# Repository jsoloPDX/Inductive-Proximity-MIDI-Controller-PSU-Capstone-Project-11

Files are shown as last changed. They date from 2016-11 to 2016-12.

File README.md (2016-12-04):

# MIDI-THEREMIN-Controller
A theremin style controller for MIDI devices
A Senior ECE practicum project for Portland State University

Background

Most electronic musical instruments are controlled by small motions such as knob-turns or button-pushes. Such actions tend to be neither as interesting to watch nor as expressive as, for example, a guitarist strumming or a drummer drumming (or a piper piping). Using hand gestures and arm motions to control musical instruments would allow more precise and expressive control of electronic instrument parameters. The theremin, an analog electronic instrument can be controlled by hand gestures, but it’s ability to interface with modern equipment is lacking and or restrictive.

Objective

Our objective is to update the Theremin-style analog instrument to contain digital features, mainly a MIDI output. This will allow it to expressively control all kinds of modern musical instruments and equipment.

HOW IT SHOULD WORK:
An analog theremin circuit will send proximity information to a Microcontroller. The Microcontroller will organize, process, and convert that information into MIDI data, which will be sent to a MIDI capable device VIA a standard MIDI or USB MIDI connector. There is some room for automation as far as built in “calibration” sequences to adjust the sensitivity of the coils. The device will be somewhat modular in design and construction, which will allow for expansion of the variety of proximity sensors used and versatility of output signals.

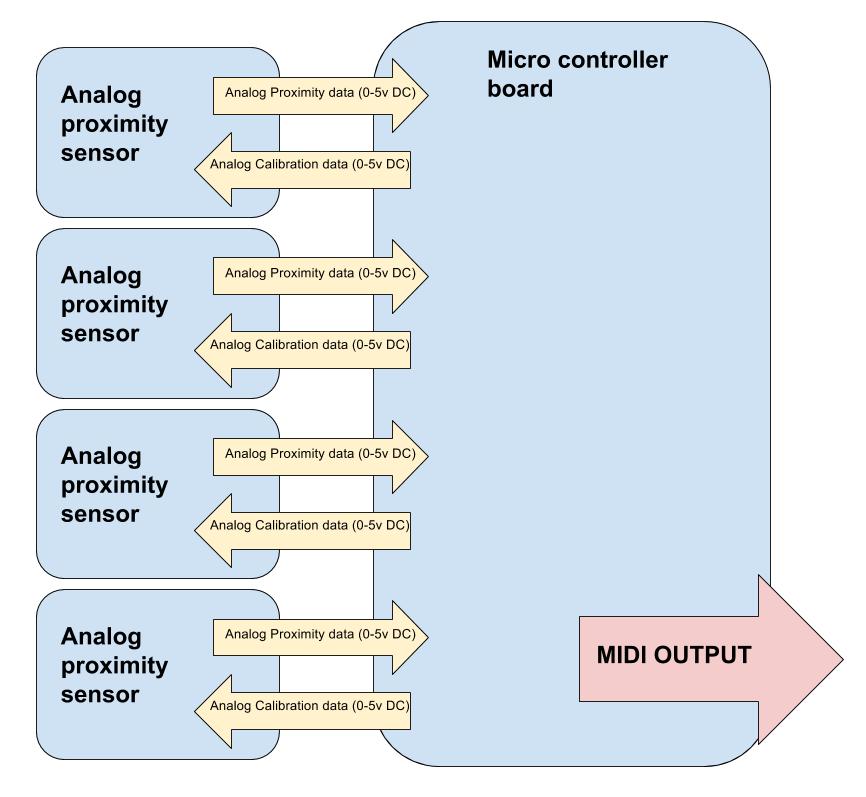
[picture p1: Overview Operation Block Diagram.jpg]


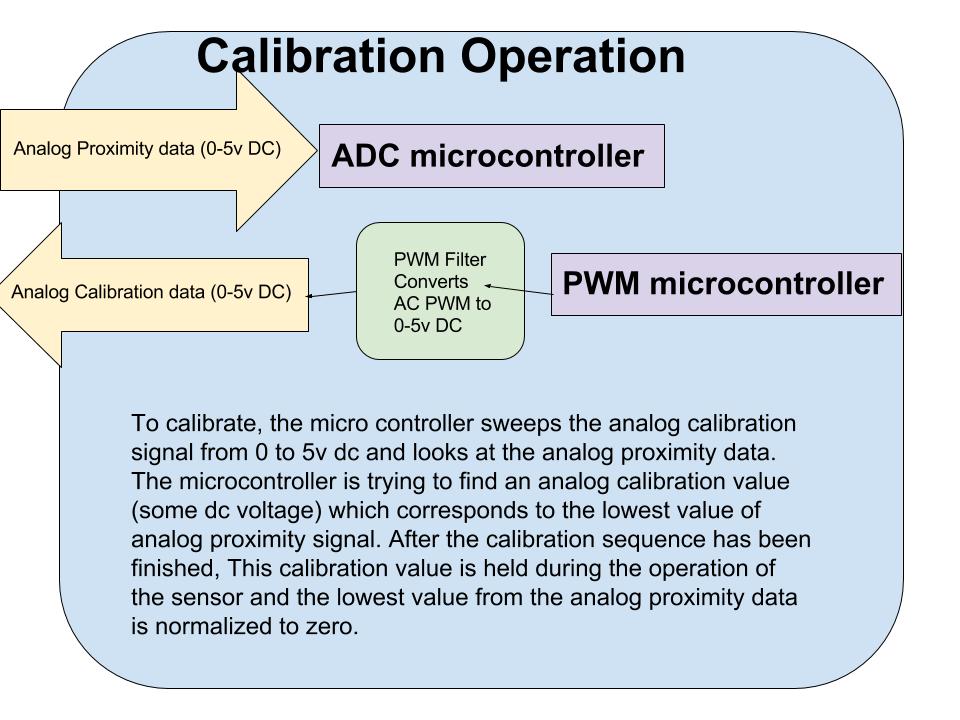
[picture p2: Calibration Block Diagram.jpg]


The code library "Arduino_MIDI_Library_v4.2.zip" is not our work and is taken from the project at: https://github.com/FortySevenEffects/arduino_midi_library/

The EagleCAD library "adafruit-Adafruit-Eagle-Library-4abf84c.zip" is not our work and is taken from the project at:
https://github.com/adafruit/Adafruit-Eagle-Library

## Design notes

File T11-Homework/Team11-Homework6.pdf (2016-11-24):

## ECE-411 Homework 6

## Practicum Team 11

Eric Bennett, Casey Montgomery, James Solonika, Charles Staffeld Instructor: Mark Faust
11/22/2016

System Tests

1. CPU Board Functional Checks
1.1. Power on indicator
1.2. Power supply voltages and current levels
1.3. Mode button and indicators
2. Sensor Board Functional Checks
2.1. Power supply voltages
2.2. Local oscillator accuracy
2.3. Pitch oscillator
2.3.1. Stable behavior
2.3.2. Detection range
2.4. Filter behavior
2.5. MISO voltage
3. Calibration Functionality Check
3.1. Run calibration function
3.2. Remeasure MISO
4. Functional Mode Checks
4.1. Mode 1
4.2. Mode 2
4.3. Mode 3
5. MIDI Control Checks
5.1. Mode 1
5.2. Mode 2
5.3. Mode 3

Test Writer: James Solonika / Charles Staffeld

Test Case Name: | CPU Board Functional Checks | Test ID#: | CPU-FC
Description: | Checks to determine if the CPU board has power and basic functionality. Does not test any user modes. | Type: | Black Box

Tester Information

Name of Tester: | | Date:
Hardware Ver: | | Time:
Setup: | CPU board should begin unplugged, 12V DC adapter with barrel jack and DMM should be available.
Step | Action | Expected Result | Pass | Fail | N/A | Comments
1 | Plug in board. | Mode 1 LED (LED 2) should light up.
2 | Measure +12V test point with DMM. | Meter should read +12V ± 0.5. Current should be < 200mA.
3 | Measure +5V test point with DMM. | Meter should read +5V ± 0.5. Current should be < 40 mA.
4 | Press mode button (SW 1) repeatedly. | LEDs will light up one at a time in this order: LED 2, 3, 4, 5, then repeat.

Overall Test Result:

Test Writer: James Solonika / Charles Staffeld

Test Case Name: | Sensor Board Functional Checks | Test ID#: | SB-FC
Description: | Checks to determine if the Sensor board can receive power and oscillate | Type: | White Box

Tester Information

Name of Tester: | | Date:
Hardware Ver: | | Time:
Setup: | CPU board plugged in and passed CPU-FC, oscilloscope, DMM and MIDI cable available
Step | Action | Expected Result | Pass | Fail | N/A | Comments
1 | Plug MIDI cable into CPU MIDI Jack 1 and MIDI jack on sensor board . | Test point “TP_LV+”” should measure +6V± 0.5V (with respect to GND as defined on the board)
2 | Plug MIDI cable into CPU MIDI Jack 1 and MIDI jack on sensor board . | Test point “TP_PV+” should measure +6V± 0.5V (with respect to GND as defined on the board)
3 | Measure test point “TP_LV-” voltage. | Voltage should be -6V ± 0.5V. (with respect to GND as defined on the board)
4 | Measure test point “TP_PV-” voltage. | Voltage should be -6V ± 0.5V. (with respect to GND as defined on the board)
5 | Scope “TP_LOSC” | Sine wave should be 460 kHz kHz ± 10kHz

6 | Scope “TP_POSC” with hand far away from antenna | Sine wave should be 460 kHz ± 10kHz
7 | Scope “TPFOUT”. With hand far away from antenna | Sine wave should be between 1Hz and 3 kHz, but stable at that frequency
8 | Scope “TPFOUT”. While moving hand near antenna | Sine wave should vary in frequency by around 1 kHz.
9 | Scope proximity voltage output “PROXIMIT Y” | A steady DC voltage.
10 | Scope MISO test point . | Should be a flat DC signal, no AC ripple.

Overall Test Result:

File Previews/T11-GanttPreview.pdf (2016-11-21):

ID | Task Mode | Task Name | Duration | Start | Finish
1 | | Presentation | 5 days | M 12/5/16 | F 12/9/16
2 | | PCB To Fab | 1 day | T 11/17/16 | T 11/17/16
3 | | Homework 6: Test Plan Due | 1 day | T 11/22/16 | T 11/22/16
4 Homework 5: System | | Design/Modeling Due | 1 day | T 11/17/16 | T 11/17/16
5 Preliminary PCB Layout Due (No | | DRC Errors) | 1 day | T 11/10/16 | T 11/10/16
6 | | Project Schedule Due | 1 day | T 11/8/16 | T 11/8/16
7 | | Software | 19 days | M 11/7/16 | T 12/1/16
8 Complete PWM Routine for | | remaining port | 4 days | M 11/7/16 | T 11/10/16
9 | | Reduce redundancies | 3 days | F 11/11/16 | T 11/15/16
10 Test that CPU can read sensor | | output | 5 days | S 11/12/16 | T 11/17/16
11 Write routine to read | | voltage | 2 days | S 11/12/16 | S 11/13/16
12 | | Test routine | 2 days | M 11/14/16 | T 11/15/16
13 | | Optimize routine | 2 days | W 11/16/16 | T 11/17/16

James Solonika

James Solonika

James Solonika

Eric Bennett

Eric Bennett

Casey Montgomery

Casey Montgomery

Casey Montgomery

2 | 5 | 8 | 11 | 14 | 17 | 20 | 23 | 26 | 29 | 2 | 5 | 8 | 11 | 14 | 17
November 2016 | December 2016

Task
Split
Milestone
Summary
Project Summary
Inactive Task
Inactive Milestone

Inactive Summary
Manual Task
Duration-only
Manual Summary Rollup
Manual Summary
Start-only
Finish-only

External Tasks
External Milestone
Deadline
Progress
Manual Progress

Page 1

Project: T11-Gantt
Date: S 11/20/16

| Mode
14 | | Write Calibration Routine | 5 days | S 11/13/16 | F 11/18/16
15 Handle button press during | | polling | 1 day | S 11/13/16 | S 11/13/16
16 | | Write LED blinking routine | 1 day | T 11/15/16 | T 11/15/16
17 Sample frequency_voltage | | input | 2 days | W 11/16/16 | T 11/17/16
18 | | Adjust output voltage | 1 day | F 11/18/16 | F 11/18/16
19 | | Write main code | 4 days | F 11/18/16 | W 11/23/16
20 | | Cpu initialization routine | 1 day | F 11/18/16 | F 11/18/16
21 | | Write button polling | 2 days | S 11/19/16 | S 11/20/16
22 frequency_voltage input | | reading | 2 days | M 11/21/16 | T 11/22/16
23 | | Call mode statement | 1 day | W 11/23/16 | W 11/23/16
24 | | Write routine for each mode | 6 days | S 11/19/16 | M 11/28/16
25 | | Write Mode 1 | 3 days | S 11/19/16 | T 11/22/16
26 | | Write Mode 2 | 3 days | W 11/23/16 | F 11/25/16

Eric Bennett

Eric Bennett

Eric Bennett

Eric Bennett

Casey Montgomery

Casey Montgomery

Casey Montgomery

Casey Montgomery

Eric Bennett

Eric Bennett

2 | 5 | 8 | 11 | 14 | 17 | 20 | 23 | 26 | 29 | 2 | 5 | 8 | 11 | 14 | 17

Task
Split
Milestone
Summary
Project Summary
Inactive Task
Inactive Milestone

Inactive Summary
Manual Task
Duration-only
Manual Summary Rollup
Manual Summary
Start-only
Finish-only

External Tasks
External Milestone
Deadline
Progress
Manual Progress

Page 2

Project: T11-Gantt
Date: S 11/20/16

| Mode
27 | | Write Mode 3 | 3 days | T 11/24/16 | S 11/26/16
28 | | Mode switching routine | 2 days | S 11/26/16 | M 11/28/16
29 | | CPU Board Hardware | 17 days | M 11/7/16 | T 11/29/16
30 | | Test Debounce | 1 day | T 11/8/16 | T 11/8/16
31 | | Test PWM Converter | 1 day | T 11/8/16 | T 11/8/16
32 | | Finalize Board Layout | 2 days | W 11/9/16 | T 11/10/16
33 | | Generate BOM | 2 days | F 11/11/16 | S 11/13/16
34 | | Create prototype CPU board | 3 days | S 11/12/16 | T 11/15/16
35 | | Sketch out board housing | 3 days | W 11/16/16 | F 11/18/16
36 | | Create board housing | 3 days | M 11/21/16 | W 11/23/16
37 | | Sensor Board Hardware | 13 days | M 11/7/16 | W 11/23/16
38 | | Finalize Board Layout | 4 days | M 11/7/16 | T 11/10/16
39 | | Generate BOM | 2 days | F 11/11/16 | S 11/13/16

Casey Montgomery

Eric Bennett

James Solonika

James Solonika

James Solonika

James Solonika

Casey Montgomery

Casey Montgomery

Casey Montgomery

Charles Staffeld

Charles Staffeld

2 | 5 | 8 | 11 | 14 | 17 | 20 | 23 | 26 | 29 | 2 | 5 | 8 | 11 | 14 | 17

Task
Split
Milestone
Summary
Project Summary
Inactive Task
Inactive Milestone

Inactive Summary
Manual Task
Duration-only
Manual Summary Rollup
Manual Summary
Start-only
Finish-only

External Tasks
External Milestone
Deadline
Progress
Manual Progress

Page 3

Project: T11-Gantt
Date: S 11/20/16

| Mode
40 | | Sketch out board housing | 4 days | T 11/15/16 | F 11/18/16 | Charles Staffeld
41 | | Create board housing | 3 days | M 11/21/16 | W 11/23/16
42 | | Testing | 16 days | T 11/15/16 | T 12/6/16
43 Test interfacing of prototype | | boards | 3 days | T 11/15/16 | T 11/17/16
44 Test functionality of sensor | | PCB | 6 days | F 11/18/16 | F 11/25/16
45 | | Test functionality of CPU PCB | 6 days | F 11/18/16 | F 11/25/16
46 | | Test interfacing of PCBs | 5 days | M 11/28/16 | F 12/2/16

Charles Staffeld

Casey Montgomery

Charles Staffeld

James Solonika

Casey Montgomery

2 | 5 | 8 | 11 | 14 | 17 | 20 | 23 | 26 | 29 | 2 | 5 | 8 | 11 | 14 | 17

Task
Split
Milestone
Summary
Project Summary
Inactive Task
Inactive Milestone

Inactive Summary
Manual Task
Duration-only
Manual Summary Rollup
Manual Summary
Start-only
Finish-only

External Tasks
External Milestone
Deadline
Progress
Manual Progress

Page 4

Project: T11-Gantt
Date: S 11/20/16

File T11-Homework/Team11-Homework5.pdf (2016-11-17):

## ECE-411 Homework 5 Practicum Team 11

Eric Bennett, Casey Montgomery, James Solonika, Charles Staffeld Instructor: Mark Faust
11/17/2016

UML Physical View:

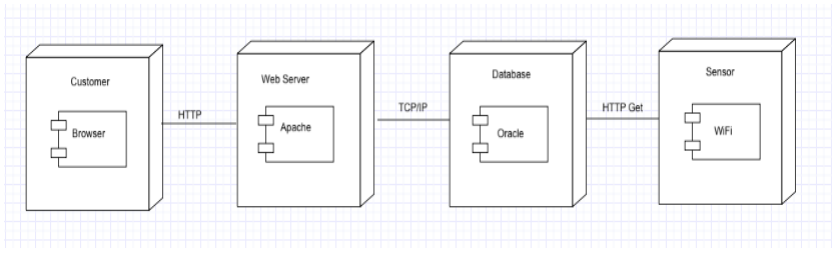
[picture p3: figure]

Simple physical system overview. Customer will not interact with the sensor directly, but pull data from a website in a browser.

UML Class Diagram:

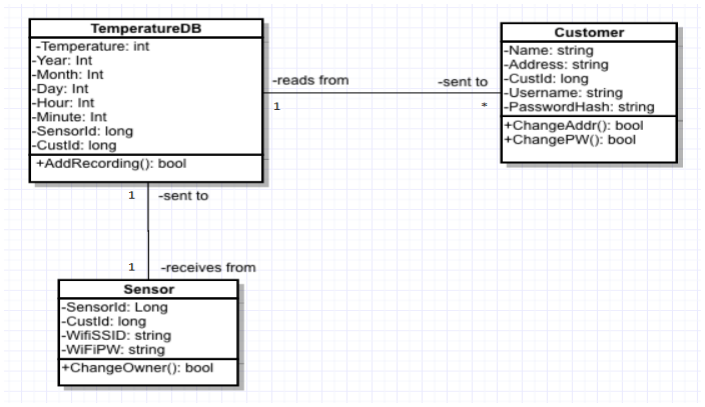
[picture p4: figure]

Decisions: CustId is included in each sensor and TemperatureDB entry to indicate the owner of the sensor and/or data. Sensor entry can be created when a sensor is manufactured and when other data are filled in during registration. WiFi information is to be stored with the sensor data to aid in adding new sensors or replacing a broken sensor. All time information is stored as separate values to simplify SQL sort and search actions.

Use Case:

Use-Case | Adding a Vaccine Temperature Sensor
Actors | Customer, Database, WebServer, Sensor
Description | This use-case occurs when a customer registers a vaccine temperature sensor. For new customers, the WebServer has them create an account, stores that information in the database, then adds their CustomerID to a sensor entry. If they are an existing customer, they are asked to verify their information then their CustomerID is added to a sensor entry. They are also asked if they would like to use the WiFi information from any of their previously registered devices.
Stimulus | Sensor registration via the WebServer
Response | Verify that sensor is connected to WiFi and can communicate with the Database

Activity View of sensor wake up and transmit:

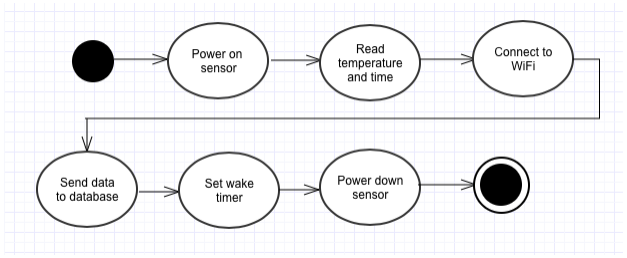
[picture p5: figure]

A wake timer is used to collect data at intervals of time instead of the sensor being woken by an outside system in order to reduce quiescent current (save power). If WiFi or the database cannot be contacted, that data its stored locally and sent with the next transmission.

HTTP GET string specification:

Upon waking, the sensor will send data to the database using a HTTP GET url in the form:

GET
/AddRecording.cgi?Temperature=value1&Year=value2&Month=value3&Day=value3&Hour=v alue4&Minute=value5&SensorId=value6

The server should be able to record all sent data into a database entry and use the SensorId to find the CustomerId that owns that sensor, then add that into the TemperatureDB entry.

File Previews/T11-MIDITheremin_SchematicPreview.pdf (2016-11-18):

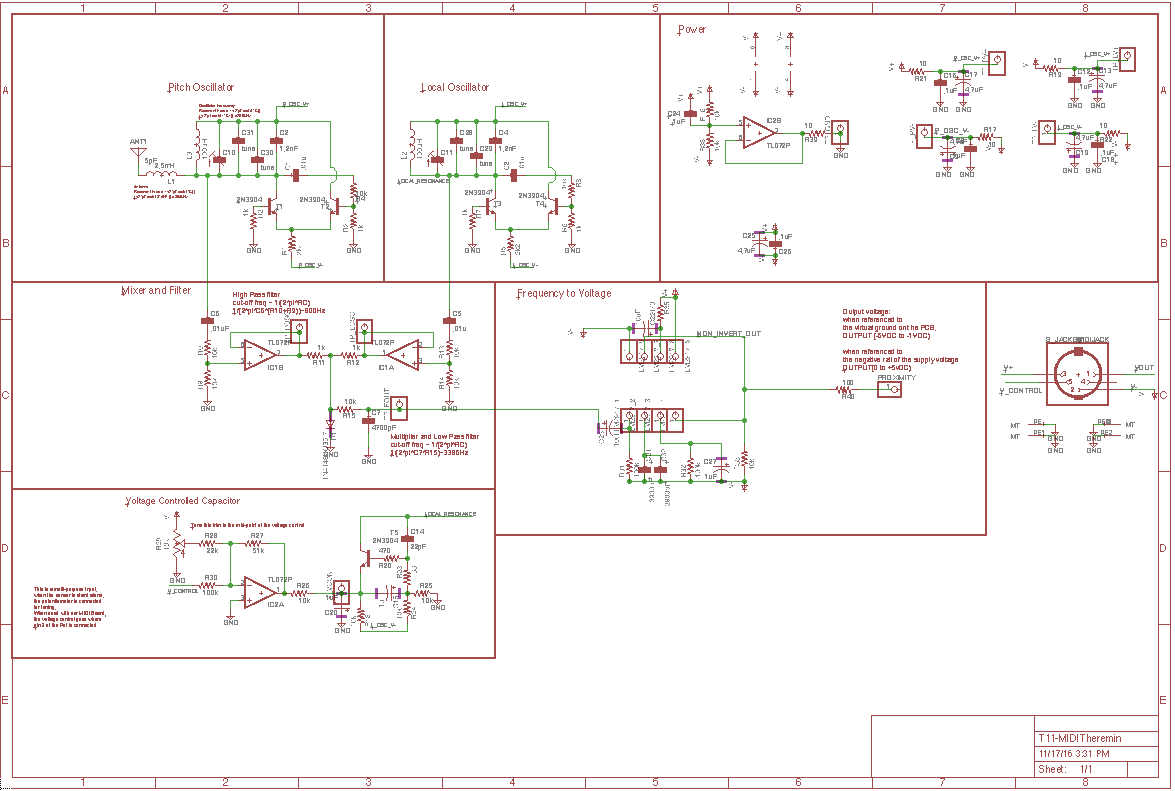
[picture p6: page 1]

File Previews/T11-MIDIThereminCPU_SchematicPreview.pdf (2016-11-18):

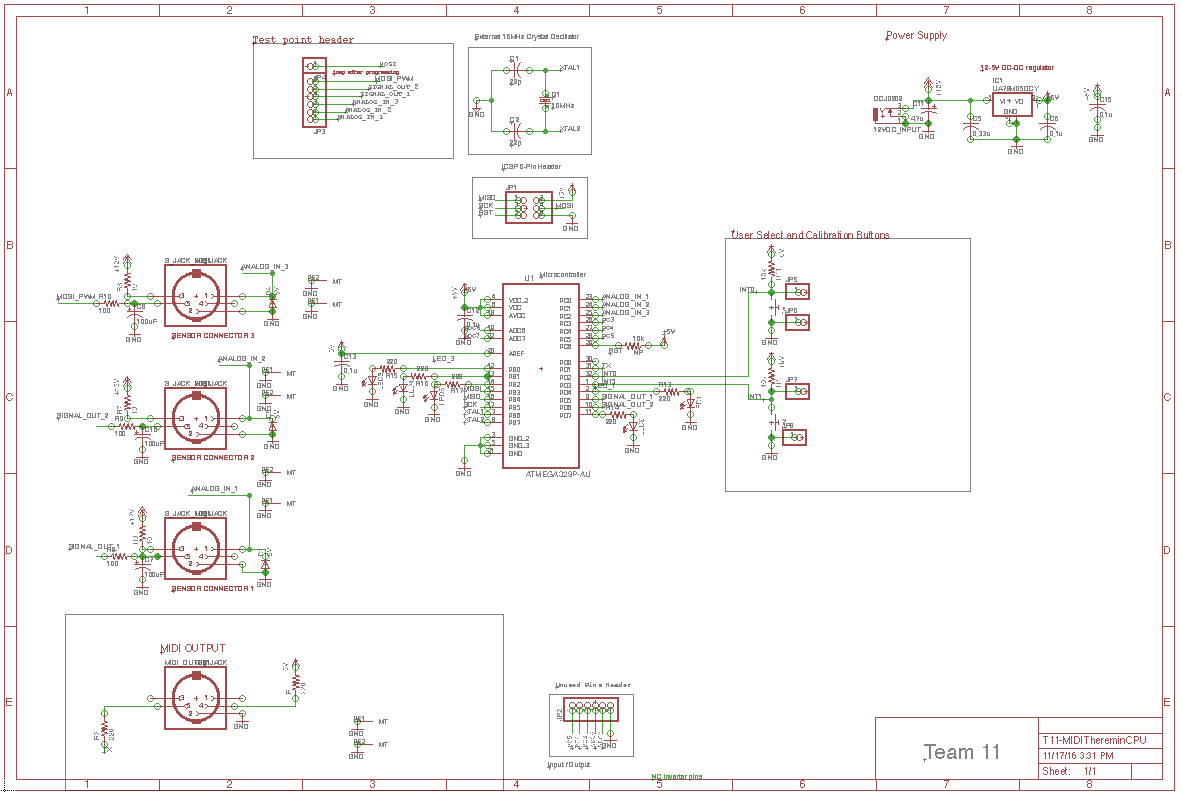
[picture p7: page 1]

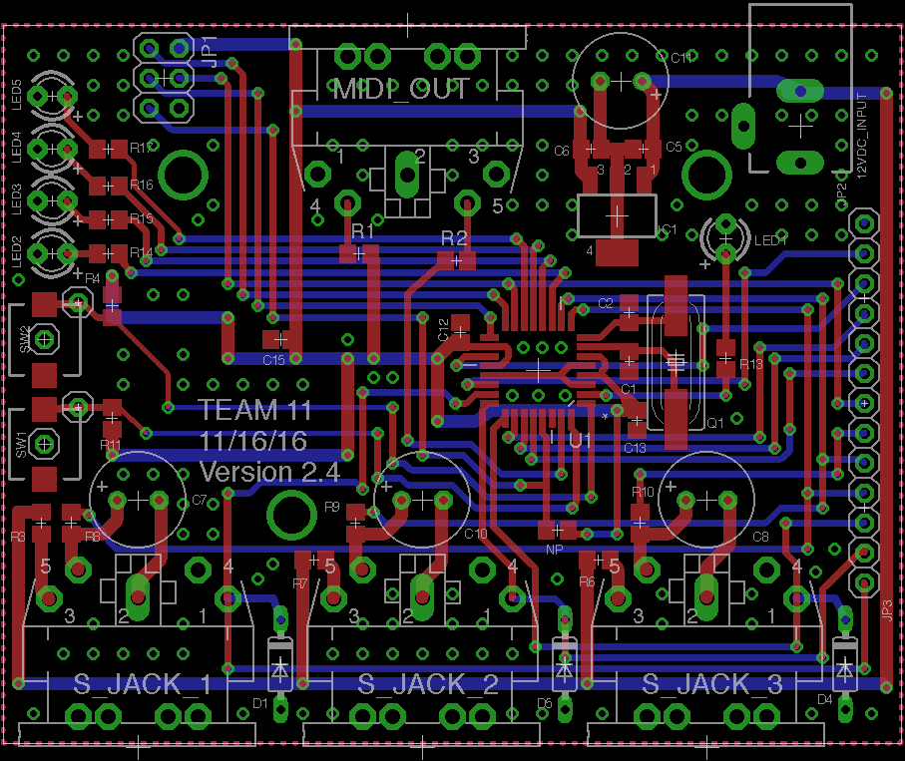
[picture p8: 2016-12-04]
Previews/T11-MIDIThereminCPUPreview.png

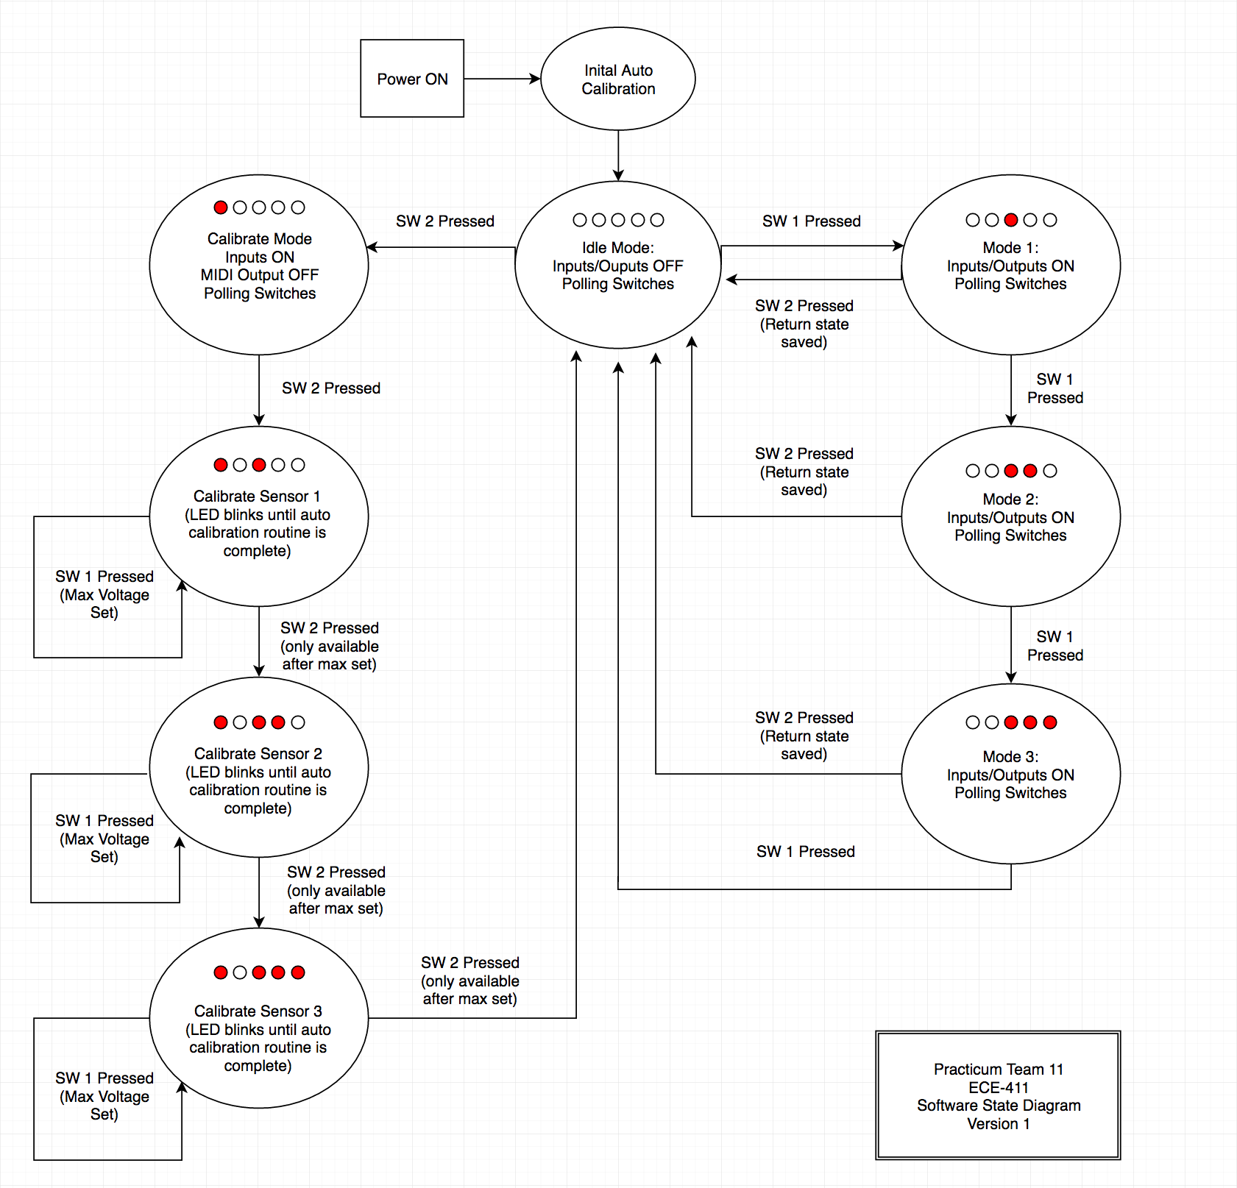
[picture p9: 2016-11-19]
T11-Documentation/T11 - Software State Diagram (Version 1).png

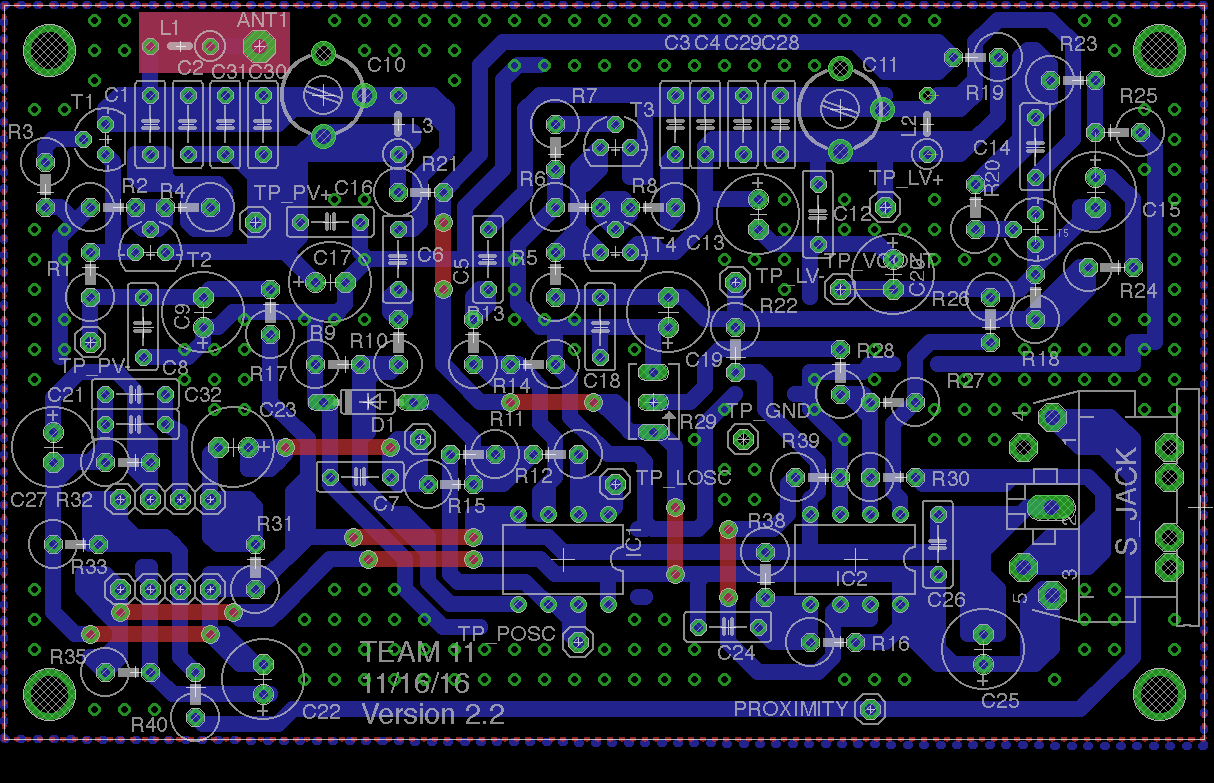
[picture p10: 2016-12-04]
Previews/T11-MIDIThereminPreview.png

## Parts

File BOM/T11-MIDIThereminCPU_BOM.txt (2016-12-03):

Partlist exported from /Users/jamessolonika/GitHub/Inductive-Proximity-MIDI-Controller/T11-MIDIThereminCPU.sch at 12/3/16 3:39 PM

Part        Value         Device                           Package               Description                                             MF MPN           OC_FARNELL OC_NEWARK PACKAGE SUPPLIER
12VDC_INPUT DCJ0202       DCJ0202                          DCJ0202               DC POWER JACK                                                            unknown    unknown                   
C1          22p           C-USC0805                        C0805                 CAPACITOR, American symbol                                                                                    
C2          22p           C-USC0805                        C0805                 CAPACITOR, American symbol                                                                                    
C5          0.33u         C-USC0805                        C0805                 CAPACITOR, American symbol                                                                                    
C6          0.1u          C-USC0805                        C0805                 CAPACITOR, American symbol                                                                                    
C7          100uF         CPOL-USE3.5-8                    E3,5-8                POLARIZED CAPACITOR, American symbol                                                                          
C8          100uF         CPOL-USE3.5-8                    E3,5-8                POLARIZED CAPACITOR, American symbol                                                                          
C10         100uF         CPOL-USE3.5-8                    E3,5-8                POLARIZED CAPACITOR, American symbol                                                                          
C11         4.7u          CPOL-USE3.5-8                    E3,5-8                POLARIZED CAPACITOR, American symbol                                                                          
C12         0.1u          C-USC0805                        C0805                 CAPACITOR, American symbol                                                                                    
C13         0.1u          C-USC0805                        C0805                 CAPACITOR, American symbol                                                                                    
C15         0.1u          C-USC0805                        C0805                 CAPACITOR, American symbol                                                                                    
D1          5V            1N4148DO35-7                     DO35-7                DIODE                                                                                                         
D4          5V            1N4148DO35-7                     DO35-7                DIODE                                                                                                         
D5          5V            1N4148DO35-7                     DO35-7                DIODE                                                                                                         
IC1         UA78M05DCY    UA78M05DCY                       SOT223                POSITIVE-VOLTAGE REGULATORS                                                                                   
JP1                       PINHD-2X3                        2X03                  PIN HEADER                                                                                                    
JP2                       PINHD-1X6                        1X06                  PIN HEADER                                                                                                    
JP3                       PINHD-1X6                        1X06                  PIN HEADER                                                                                                    
JP4                       PINHD-1X1                        1X01                  PIN HEADER                                                                                                    
JP5                       PINHD-1X1                        1X01                  PIN HEADER                                                                                                    
JP6                       PINHD-1X1                        1X01                  PIN HEADER                                                                                                    
JP7                       PINHD-1X1                        1X01                  PIN HEADER                                                                                                    
JP8                       PINHD-1X1                        1X01                  PIN HEADER                                                                                                    
LED1                      LED3MM                           LED3MM                LED                                                                                                           
LED2                      LED3MM                           LED3MM                LED                                                                                                           
LED3                      LED3MM                           LED3MM                LED                                                                                                           
LED4                      LED3MM                           LED3MM                LED                                                                                                           
LED5                      LED3MM                           LED3MM                LED                                                                                                           
MIDI_OUT    MIDIJACK      MIDIJACK                         CP-2350               DIN 5 jack also known as MIDI jack                                                                            
NP          10k           R-US_R0805                       R0805                 RESISTOR, American symbol                                                                                     
Q1          16MHz         CRYSTALSM49                      SM49                  CRYSTAL                                                                  unknown    unknown                   
R1          220           R-US_R0805                       R0805                 RESISTOR, American symbol                                                                                     
R2          220           R-US_M0805                       M0805                 RESISTOR, American symbol                                                                                     
R3          10            R-US_R0805                       R0805                 RESISTOR, American symbol                                                                                     
R4          10k           R-US_R0805                       R0805                 RESISTOR, American symbol                                                                                     
R6          10            R-US_M0805                       M0805                 RESISTOR, American symbol                                                                                     
R7          10            R-US_R0805                       R0805                 RESISTOR, American symbol                                                                                     
R8          100           R-US_R0805                       R0805                 RESISTOR, American symbol                                                                                     
R9          100           R-US_R0805                       R0805                 RESISTOR, American symbol                                                                                     
R10         100           R-US_M0805                       M0805                 RESISTOR, American symbol                                                                                     
R11         10k           R-US_R0805                       R0805                 RESISTOR, American symbol                                                                                     
R13         220           R-US_R0805                       R0805                 RESISTOR, American symbol                                                                                     
R14         220           R-US_R0805                       R0805                 RESISTOR, American symbol                                                                                     
R15         220           R-US_R0805                       R0805                 RESISTOR, American symbol                                                                                     
R16         220           R-US_R0805                       R0805                 RESISTOR, American symbol                                                                                     
R17         220           R-US_R0805                       R0805                 RESISTOR, American symbol                                                                                     
SW1                       SWITCH_PUSHBUTTONSOFTTOUCHSMD_SJ PUSHBUTTON_SMD_SJ     Buttons                                                                                                       
SW2                       SWITCH_PUSHBUTTONSOFTTOUCHSMD_SJ PUSHBUTTON_SMD_SJ     Buttons                                                                                                       
S_JACK_1    MIDIJACK      MIDIJACK                         CP-2350               DIN 5 jack also known as MIDI jack                                                                            
S_JACK_2    MIDIJACK      MIDIJACK                         CP-2350               DIN 5 jack also known as MIDI jack                                                                            
S_JACK_3    MIDIJACK      MIDIJACK                         CP-2350               DIN 5 jack also known as MIDI jack                                                                            
U1          ATMEGA328P-AU ATMEGA328P-AU                    QFP80P900X900X120-32N 8-bit Microcontroller with In-System Programmable Flash    ATMEGA328P-AU 1715486    14R4631   TQFP-32 Atmel

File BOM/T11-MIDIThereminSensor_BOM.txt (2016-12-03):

Partlist exported from /Users/jamessolonika/GitHub/Inductive-Proximity-MIDI-Controller/T11-MIDITheremin.sch at 12/3/16 3:37 PM

Part      Value        Device          Package       Description                          
ANT1      5pF          ANTENNA         PAD-01        Antenna                              
C1        .01u         C-EU050-025X075 C050-025X075  CAPACITOR, European symbol           
C2        1.2nF        C-EU050-025X075 C050-025X075  CAPACITOR, European symbol           
C3        .01u         C-EU050-025X075 C050-025X075  CAPACITOR, European symbol           
C4        1.2nF        C-EU050-025X075 C050-025X075  CAPACITOR, European symbol           
C5        .01u         C-EU050-025X075 C050-025X075  CAPACITOR, European symbol           
C6        .01uF        C-EU050-025X075 C050-025X075  CAPACITOR, European symbol           
C7        4700pF       C-EU050-025X075 C050-025X075  CAPACITOR, European symbol           
C8        .1uF         C-EU050-025X075 C050-025X075  CAPACITOR, European symbol           
C9        4.7uF        CPOL-USE2.5-7   E2,5-7        POLARIZED CAPACITOR, American symbol 
C10                    C-TRIMM3040.427 CTRIM3040.427 Trimm capacitor                      
C11                    C-TRIMM3040.427 CTRIM3040.427 Trimm capacitor                      
C12       .1uF         C-EU050-025X075 C050-025X075  CAPACITOR, European symbol           
C13       4.7uF        CPOL-USE2.5-7   E2,5-7        POLARIZED CAPACITOR, American symbol 
C14       22pF         C-EU050-025X075 C050-025X075  CAPACITOR, European symbol           
C15       1uF          CPOL-USE2.5-7   E2,5-7        POLARIZED CAPACITOR, American symbol 
C16       .1uF         C-EU050-025X075 C050-025X075  CAPACITOR, European symbol           
C17       4.7uF        CPOL-USE2.5-7   E2,5-7        POLARIZED CAPACITOR, American symbol 
C18       .1uF         C-EU050-025X075 C050-025X075  CAPACITOR, European symbol           
C19       4.7uF        CPOL-USE2.5-7   E2,5-7        POLARIZED CAPACITOR, American symbol 
C20       1uF          CPOL-USE2.5-7   E2,5-7        POLARIZED CAPACITOR, American symbol 
C21       3900pF       C-EU050-025X075 C050-025X075  CAPACITOR, European symbol           
C22       10uF         CPOL-USE2.5-7   E2,5-7        POLARIZED CAPACITOR, American symbol 
C23       10uF         CPOL-USE2.5-7   E2,5-7        POLARIZED CAPACITOR, American symbol 
C24       .1uF         C-EU050-025X075 C050-025X075  CAPACITOR, European symbol           
C25       4.7uF        CPOL-USE2.5-7   E2,5-7        POLARIZED CAPACITOR, American symbol 
C26       .1uF         C-EU050-025X075 C050-025X075  CAPACITOR, European symbol           
C27       1uF          CPOL-USE2.5-7   E2,5-7        POLARIZED CAPACITOR, American symbol 
C28       tune         C-EU050-025X075 C050-025X075  CAPACITOR, European symbol           
C29       tune         C-EU050-025X075 C050-025X075  CAPACITOR, European symbol           
C30       tune         C-EU050-025X075 C050-025X075  CAPACITOR, European symbol           
C31       tune         C-EU050-025X075 C050-025X075  CAPACITOR, European symbol           
C32       3900pF       C-EU050-025X075 C050-025X075  CAPACITOR, European symbol           
D1        1N4148DO35-7 1N4148DO35-7    DO35-7        DIODE                                
IC1       TL072P       TL072P          DIL08         OP AMP                               
IC2       TL072P       TL072P          DIL08         OP AMP                               
L1        2.5mH        L-US0207/5V     0207/5V       INDUCTOR, American symbol            
L2        100uH        L-US0207/5V     0207/5V       INDUCTOR, American symbol            
L3        100uH        L-US0207/5V     0207/5V       INDUCTOR, American symbol            
LM2917_1               PINHD-1X1       1X01          PIN HEADER                           
LM2917_2               PINHD-1X1       1X01          PIN HEADER                           
LM2917_3               PINHD-1X1       1X01          PIN HEADER                           
LM2917_4               PINHD-1X1       1X01          PIN HEADER                           
LM2917_5               PINHD-1X1       1X01          PIN HEADER                           
LM2917_6               PINHD-1X1       1X01          PIN HEADER                           
LM2917_7               PINHD-1X1       1X01          PIN HEADER                           
LM2917_8               PINHD-1X1       1X01          PIN HEADER                           
PROXIMITY              PINHD-1X1       1X01          PIN HEADER                           
R1        2k2          R-US_0411/3V    0411V         RESISTOR, American symbol            
R2        1k           R-US_0411/3V    0411V         RESISTOR, American symbol            
R3        1k           R-US_0411/3V    0411V         RESISTOR, American symbol            
R4        10k          R-US_0411/3V    0411V         RESISTOR, American symbol            
R5        2k2          R-US_0411/3V    0411V         RESISTOR, American symbol            
R6        1k           R-US_0411/3V    0411V         RESISTOR, American symbol            
R7        1k           R-US_0411/3V    0411V         RESISTOR, American symbol            
R8        10k          R-US_0411/3V    0411V         RESISTOR, American symbol            
R9        10k          R-US_0411/3V    0411V         RESISTOR, American symbol            
R10       10k          R-US_0411/3V    0411V         RESISTOR, American symbol            
R11       1k           R-US_0411/3V    0411V         RESISTOR, American symbol            
R12       1k           R-US_0411/3V    0411V         RESISTOR, American symbol            
R13       10k          R-US_0411/3V    0411V         RESISTOR, American symbol            
R14       10k          R-US_0411/3V    0411V         RESISTOR, American symbol            
R15       10k          R-US_0411/3V    0411V         RESISTOR, American symbol            
R16       10k          R-US_0411/3V    0411V         RESISTOR, American symbol            
R17       10           R-US_0411/3V    0411V         RESISTOR, American symbol            
R18       10k          R-US_0411/3V    0411V         RESISTOR, American symbol            
R19       10           R-US_0411/3V    0411V         RESISTOR, American symbol            
R20       470          R-US_0411/3V    0411V         RESISTOR, American symbol            
R21       10           R-US_0411/3V    0411V         RESISTOR, American symbol            
R22       10           R-US_0411/3V    0411V         RESISTOR, American symbol            
R23       33           R-US_0411/3V    0411V         RESISTOR, American symbol            
R24       10k          R-US_0411/3V    0411V         RESISTOR, American symbol            
R25       10k          R-US_0411/3V    0411V         RESISTOR, American symbol            
R26       10k          R-US_0411/3V    0411V         RESISTOR, American symbol            
R27       51k          R-US_0411/3V    0411V         RESISTOR, American symbol            
R28       22k          R-US_0411/3V    0411V         RESISTOR, American symbol            
R29       10k          TRIM_US-B64Y    B64Y          POTENTIOMETER                        
R30       100k         R-US_0411/3V    0411V         RESISTOR, American symbol            
R31       100k         R-US_0411/3V    0411V         RESISTOR, American symbol            
R32       100k         R-US_0411/3V    0411V         RESISTOR, American symbol            
R33       10k          R-US_0411/3V    0411V         RESISTOR, American symbol            
R35       470          R-US_0411/3V    0411V         RESISTOR, American symbol            
R38       10k          R-US_0411/3V    0411V         RESISTOR, American symbol            
R39       10           R-US_0411/3V    0411V         RESISTOR, American symbol            
R40       100          R-US_0411/3V    0411V         RESISTOR, American symbol            
S_JACK    MIDIJACK     MIDIJACK        CP-2350       DIN 5 jack also known as MIDI jack   
T1        2N3904       2N3904          TO92          NPN TRANSISTOR                       
T2        2N3904       2N3904          TO92          NPN TRANSISTOR                       
T3        2N3904       2N3904          TO92          NPN TRANSISTOR                       
T4        2N3904       2N3904          TO92          NPN TRANSISTOR                       
T5        2N3904       2N3904          TO92          NPN TRANSISTOR                       
TP_FOUT                PINHD-1X1       1X01          PIN HEADER                           
TP_GND                 PINHD-1X1       1X01          PIN HEADER                           
TP_LOSC                PINHD-1X1       1X01          PIN HEADER                           
TP_LV+                 PINHD-1X1       1X01          PIN HEADER                           
TP_LV-                 PINHD-1X1       1X01          PIN HEADER                           
TP_POSC                PINHD-1X1       1X01          PIN HEADER                           
TP_PV+                 PINHD-1X1       1X01          PIN HEADER                           
TP_PV-                 PINHD-1X1       1X01          PIN HEADER                           
TP_VCONT               PINHD-1X1       1X01          PIN HEADER

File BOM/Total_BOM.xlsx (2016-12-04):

CPU Board
Qty | Value | Device | Package / Device Number | Cost Per | Total Cost
1 |  | CPU Board | PCB | 12 | 12
1 |  | Case | 3D Print |  | 0
5 |  | LED | LED 3mm | 0.1 | 0.5
1 | 16MHz | Crystal | SM49 | 0.15 | 0.15
1 |  | DC Jack | DCJ0202 | 0.75 | 0.75
1 | 4.7u | Electrolytic Capacitor | E3,5-8 | 0.05 | 0.05
3 | 100u | Electrolytic Capacitor | E3,5-8 | 0.05 | 0.15
1 |  | Microcontroller | ATMEGA328P-AU | 1.8 | 1.8
4 |  | Midi Jack | CP-2350 | 1 | 4
5 |  | Pin Header | 1X01 | 0.02 | 0.1
2 |  | Pin Header | 1X06 | 0.02 | 0.04
1 |  | Pin Header | 2X03 | 0.02 | 0.02
2 |  | Push Button Switch | PUSHBUTTON_SMD_SJ | 0.1 | 0.2
2 | 22p | SMT Capacitor | C0805 | 0.04 | 0.08
4 | 0.1u | SMT Capacitor | C0805 | 0.04 | 0.16
1 | 0.33u | SMT Capacitor | C0805 | 0.04 | 0.04
1 | 10 | SMT Resistor | M0805 | 0.04 | 0.04
2 | 10 | SMT Resistor | R0805 | 0.04 | 0.08
1 | 100 | SMT Resistor | M0805 | 0.04 | 0.04
2 | 100 | SMT Resistor | R0805 | 0.04 | 0.08
1 | 220 | SMT Resistor | M0805 | 0.04 | 0.04
6 | 200 | SMT Resistor | R0805 | 0.04 | 0.24
3 | 10k | SMT Resistor | R0805 | 0.04 | 0.12
6 |  | Trimm Capacitor | CTRIM3040.427 | 0.25 | 1.5
1 |  | Voltage Regulator | UA78M05DCY | 0.6 | 0.6
3 | 5V | Zener Diode | DO35-7 | 0.1 | 0.3 | TOTAL | 23.08
Sensor Boards
Qty | Value | Device | Package / Device Number | Cost Per | Total Cost
3 |  | Sensor Board | PCB | 16.5 | 49.5
3 |  | Antenna | Copper Pipe | 1.65 | 4.95
3 |  | Case | Woodcut | 1 | 3
12 | 0.01u | Ceramic Capacitor | C050-025X075 | 0.02 | 0.24
18 | 0.1u | Ceramic Capacitor | C050-025X075 | 0.02 | 0.36
6 | 1.2n | Ceramic Capacitor | C050-025X075 | 0.02 | 0.12
3 | 22p | Ceramic Capacitor | C050-025X075 | 0.02 | 0.06
6 | 3900p | Ceramic Capacitor | C050-025X075 | 0.02 | 0.12
3 | 4700p | Ceramic Capacitor | C050-025X075 | 0.02 | 0.06
3 |  | Diode | 1N4148 | 0.1 | 0.3
6 | 10u | Electrolytic Capacitor | E2,5-7 | 0.05 | 0.3
9 | 1u | Electrolytic Capacitor | E2,5-7 | 0.05 | 0.45
15 | 4.7u | Electrolytic Capacitor | E2,5-7 | 0.05 | 0.75
3 |  | Frequency to Voltage | LM2917 | 0.9 | 2.7
6 | 100u | Inductor | 0207/5V | 0.15 | 0.9
3 | 2.5m | Inductor | 0207/5V | 0.15 | 0.45
3 |  | Midi Jack | CP-2350 | 1 | 3
6 |  | OP-Amp | TL072P | 0.6 | 3.6
3 | 10k | Potentiometer | B64Y | 0.25 | 0.75
15 | 10 | Resistor | 0411V | 0.02 | 0.3
3 | 100 | Resistor | 0411V | 0.02 | 0.06
9 | 100k | Resistor | 0411V | 0.02 | 0.18
42 | 10k | Resistor | 0411V | 0.02 | 0.84
18 | 1k | Resistor | 0411V | 0.02 | 0.36
3 | 22k | Resistor | 0411V | 0.02 | 0.06
6 | 2.2k | Resistor | 0411V | 0.02 | 0.12
3 | 33 | Resistor | 0411V | 0.02 | 0.06
6 | 470 | Resistor | 0411V | 0.02 | 0.12
3 | 51k | Resistor | 0411V | 0.02 | 0.06
15 |  | Transistor | 2N3904 | 0.25 | 3.75 | TOTAL | 77.52

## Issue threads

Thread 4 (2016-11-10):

TEST PWM FILTER

CharlesStaffeld, 2016-11-10:
We need to breadboard and test the filter which converts the PWM from the microcontroller into DC voltage. LTSpice simulation works with values of 100ohms and 100uF

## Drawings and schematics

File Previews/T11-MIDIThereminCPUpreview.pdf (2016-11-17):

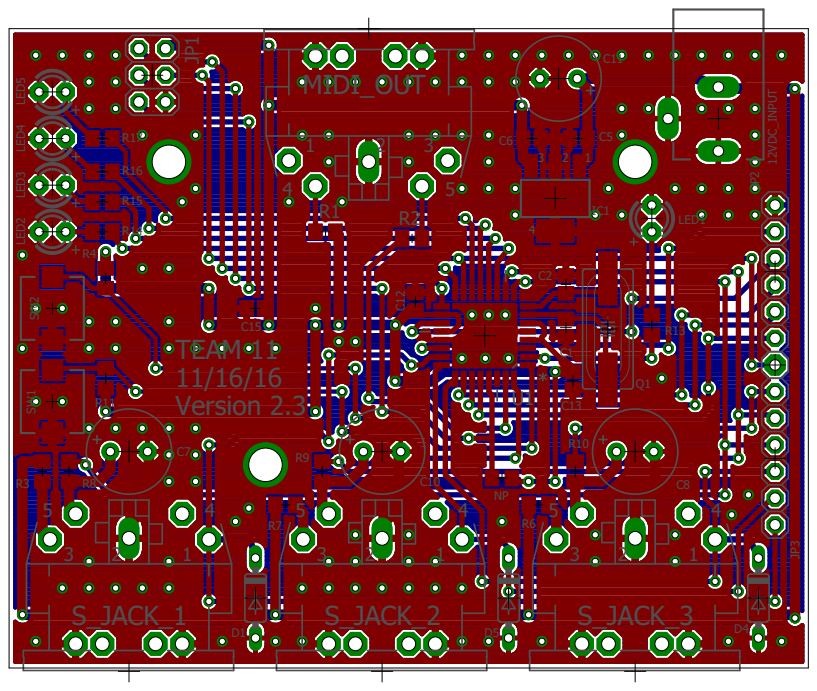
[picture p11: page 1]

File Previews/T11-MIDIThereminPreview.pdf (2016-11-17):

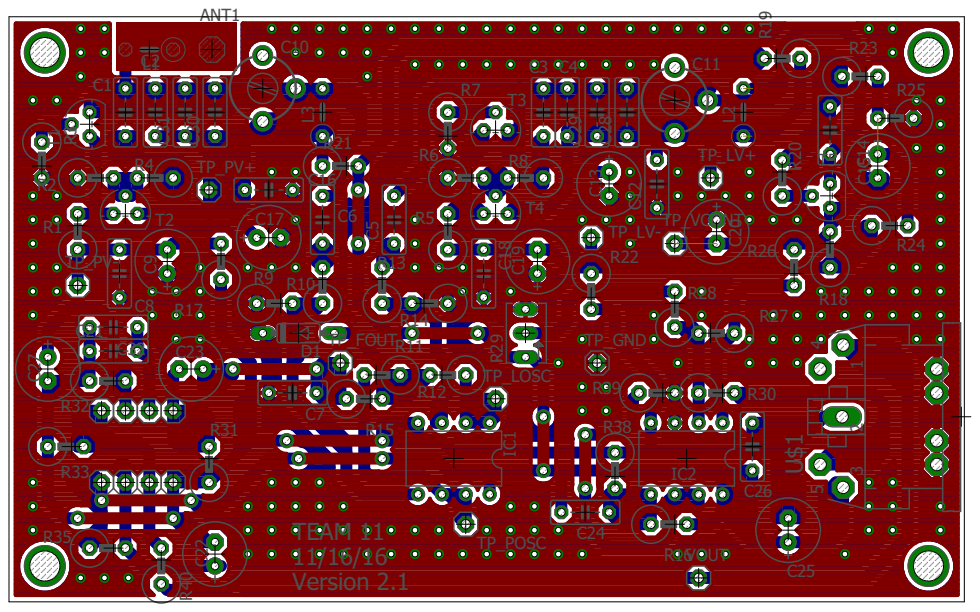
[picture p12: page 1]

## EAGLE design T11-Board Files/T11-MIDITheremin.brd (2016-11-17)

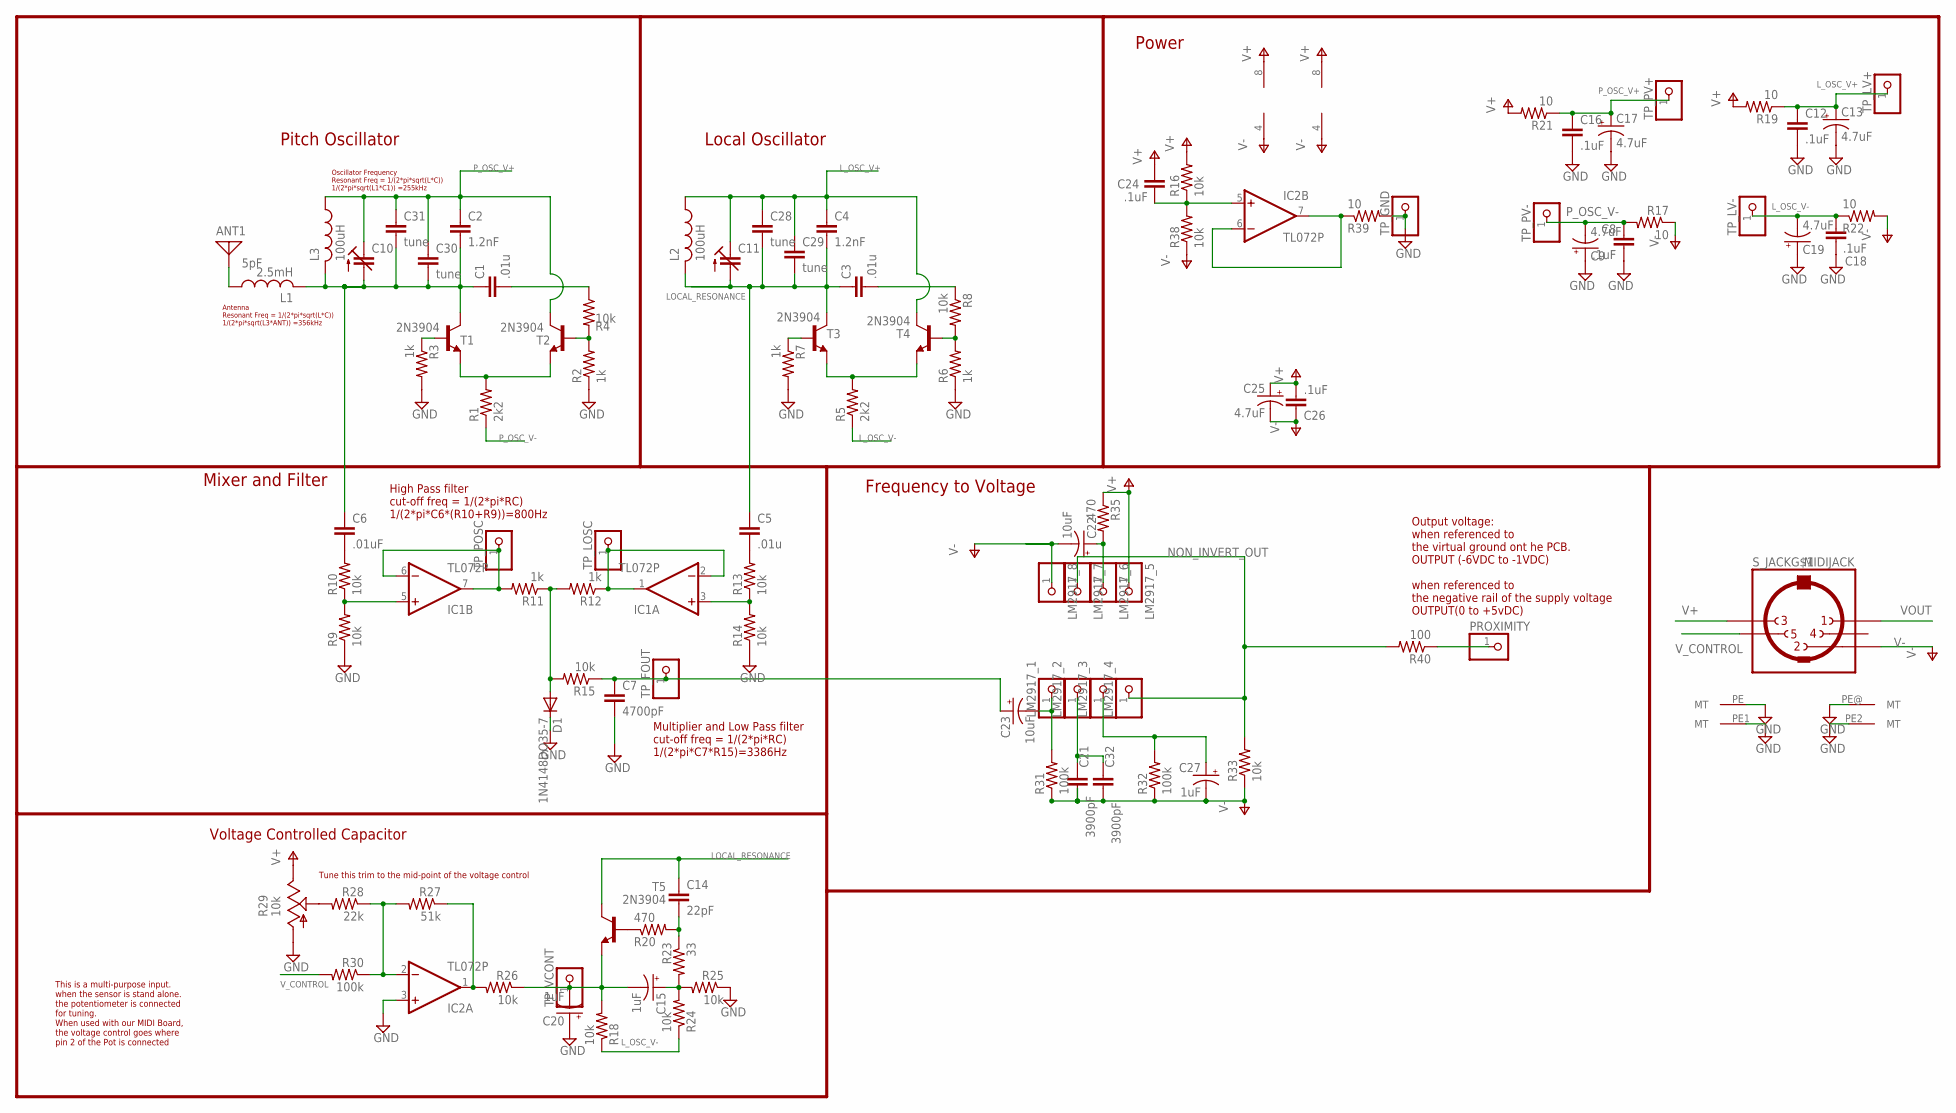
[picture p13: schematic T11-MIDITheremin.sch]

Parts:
ANT1: 5pF; PAD-01
C1, C3, C5: .01u; C050-025X075
C2, C4: 1.2nF; C050-025X075
C6: .01uF; C050-025X075
C7: 4700pF; C050-025X075
C8, C12, C16, C18, C24, C26: .1uF; C050-025X075
C9, C13, C17, C19, C25: 4.7uF; E2,5-7
C10, C11: C-TRIMM3040.427; CTRIM3040.427
C14: 22pF; C050-025X075
C15, C20, C27: 1uF; E2,5-7
C21, C32: 3900pF; C050-025X075
C22, C23: 10uF; E2,5-7
C28, C29, C30, C31: tune; C050-025X075
D1: 1N4148DO35-7; DO35-7
IC1, IC2: TL072P; DIL08
L1: 2.5mH; 0207/5V
L2, L3: 100uH; 0207/5V
LM2917_1, LM2917_2, LM2917_3, LM2917_4, LM2917_5, LM2917_6, LM2917_7, LM2917_8: PINHD-1X1; 1X01
PROXIMITY: PINHD-1X1; 1X01
R1, R5: 2k2; 0411V
R2, R3, R6, R7, R11, R12: 1k; 0411V
R4, R8, R9, R10, R13, R14, R15, R16, R18, R24, R25, R26, R33, R38: 10k; 0411V
R17, R19, R21, R22, R39: 10; 0411V
R20, R35: 470; 0411V
R23: 33; 0411V
R27: 51k; 0411V
R28: 22k; 0411V
R29: 10k; B64Y
R30, R31, R32: 100k; 0411V
R40: 100; 0411V
S_JACK: MIDIJACK; CP-2350
T1, T2, T3, T4, T5: 2N3904; TO92
TP_FOUT: PINHD-1X1; 1X01
TP_GND: PINHD-1X1; 1X01
TP_LOSC: PINHD-1X1; 1X01
TP_LV+: PINHD-1X1; 1X01
TP_LV-: PINHD-1X1; 1X01
TP_POSC: PINHD-1X1; 1X01
TP_PV+: PINHD-1X1; 1X01
TP_PV-: PINHD-1X1; 1X01
TP_VCONT: PINHD-1X1; 1X01

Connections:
GND: C7.2, C8.2, C9.+, C12.2, C13.-, C16.2, C17.-, C18.2, C19.+, C20.+, D1.C, IC2.3 (+IN), R2.1, R3.2, R6.1, R7.2, R9.1, R14.1, R25.1, R29.A, R39.2, S_JACK.PE (MT), S_JACK.PE1 (MT), S_JACK.PE2 (MT), S_JACK.PE@ (MT), TP_GND.1
LOCAL_RESONANCE: C3.1, C4.2, C5.1, C11.2 (A), C14.1, C28.2, C29.2, L2.2, T3.1 (C), T5.1 (C)
L_OSC_V+: C4.1, C11.1A (E), C12.1, C13.+, C28.1, C29.1, L2.1, R19.1, T4.1 (C), TP_LV+.1
L_OSC_V-: C18.1, C19.-, R5.1, R18.1, R22.1, R24.1, TP_LV-.1
unnamed: R1.2, T1.3 (E), T2.3 (E)
unnamed: R2.2, R4.2, T2.2 (B)
unnamed: R3.1, T1.2 (B)
unnamed: C1.1, C2.2, C6.1, C10.2 (A), C30.2, C31.2, L1.2, L3.2, T1.1 (C)
unnamed: C1.2, R4.1
unnamed: R5.2, T3.3 (E), T4.3 (E)
unnamed: R6.2, R8.2, T4.2 (B)
unnamed: R7.1, T3.2 (B)
unnamed: C15.-, C20.-, R18.2, R26.1, T5.3 (E), TP_VCONT.1
unnamed: C5.2, R13.2
unnamed: IC1.6 (-IN), IC1.7 (OUT), R11.2, TP_POSC.1
unnamed: IC1.1 (OUT), IC1.2 (-IN), R12.1, TP_LOSC.1
unnamed: IC1.5 (+IN), R9.2, R10.1
unnamed: D1.A, R11.1, R12.2, R15.2
unnamed: IC1.3 (+IN), R13.1, R14.2
unnamed: C3.2, R8.1
unnamed: C6.2, R10.2
unnamed: C7.1, C23.+, R15.1, TP_FOUT.1
unnamed: C21.1, C32.1, LM2917_2.1
unnamed: R20.1, T5.2 (B)
unnamed: C14.2, R20.2, R23.1
unnamed: C15.+, R23.2, R24.2, R25.2
unnamed: IC2.1 (OUT), R26.2, R27.1
unnamed: IC2.2 (-IN), R27.2, R28.1, R30.1
unnamed: R28.2, R29.S
unnamed: IC2.6 (-IN), IC2.7 (OUT), R39.1
unnamed: ANT1.1, L1.1
unnamed: C22.+, LM2917_6.1, R35.2
unnamed: C27.+, LM2917_3.1, R32.2
unnamed: C23.-, LM2917_1.1, R31.2
unnamed: C24.2, IC2.5 (+IN), R16.1, R38.2
NON_INVERT_OUT: LM2917_4.1, LM2917_7.1, R33.2, R40.2
P_OSC_V+: C2.1, C10.1A (E), C16.1, C17.+, C30.1, C31.1, L3.1, R21.1, T2.1 (C), TP_PV+.1
P_OSC_V-: C8.1, C9.-, R1.1, R17.2, TP_PV-.1
V+: C24.1, C25.+, C26.2, IC1.8 (V+), IC2.8 (V+), LM2917_5.1, R16.2, R19.2, R21.2, R29.E, R35.1, S_JACK.3
V-: C21.2, C22.-, C25.-, C26.1, C27.-, C32.2, IC1.4 (V-), IC2.4 (V-), LM2917_8.1, R17.1, R22.2, R31.1, R32.1, R33.1, R38.1, S_JACK.2
VOUT: PROXIMITY.1, R40.1, S_JACK.1
V_CONTROL: R30.2, S_JACK.5

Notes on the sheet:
Pitch Oscillator
Local Oscillator
High Pass filter cut-off freq = 1/(2*pi*RC) 1/(2*pi*C6*(R10+R9))=800Hz
Multiplier and Low Pass filter cut-off freq = 1/(2*pi*RC) 1/(2*pi*C7*R15)=3386Hz
Oscillator Frequency Resonant Freq = 1/(2*pi*sqrt(L*C)) 1/(2*pi*sqrt(L1*C1)) =255kHz
Antenna Resonant Freq = 1/(2*pi*sqrt(L*C)) 1/(2*pi*sqrt(L3*ANT)) =356kHz
Mixer and Filter
Frequency to Voltage
Voltage Controlled Capacitor
Power
Tune this trim to the mid-point of the voltage control
This is a multi-purpose input. when the sensor is stand alone. the potentiometer is connected for tuning. When used with our MIDI Board, the voltage control goes where pin 2 of the Pot is connected
Output voltage: when referenced to the virtual ground ont he PCB. OUTPUT (-6VDC to -1VDC) when referenced to the negative rail of the supply voltage OUTPUT(0 to +5vDC)

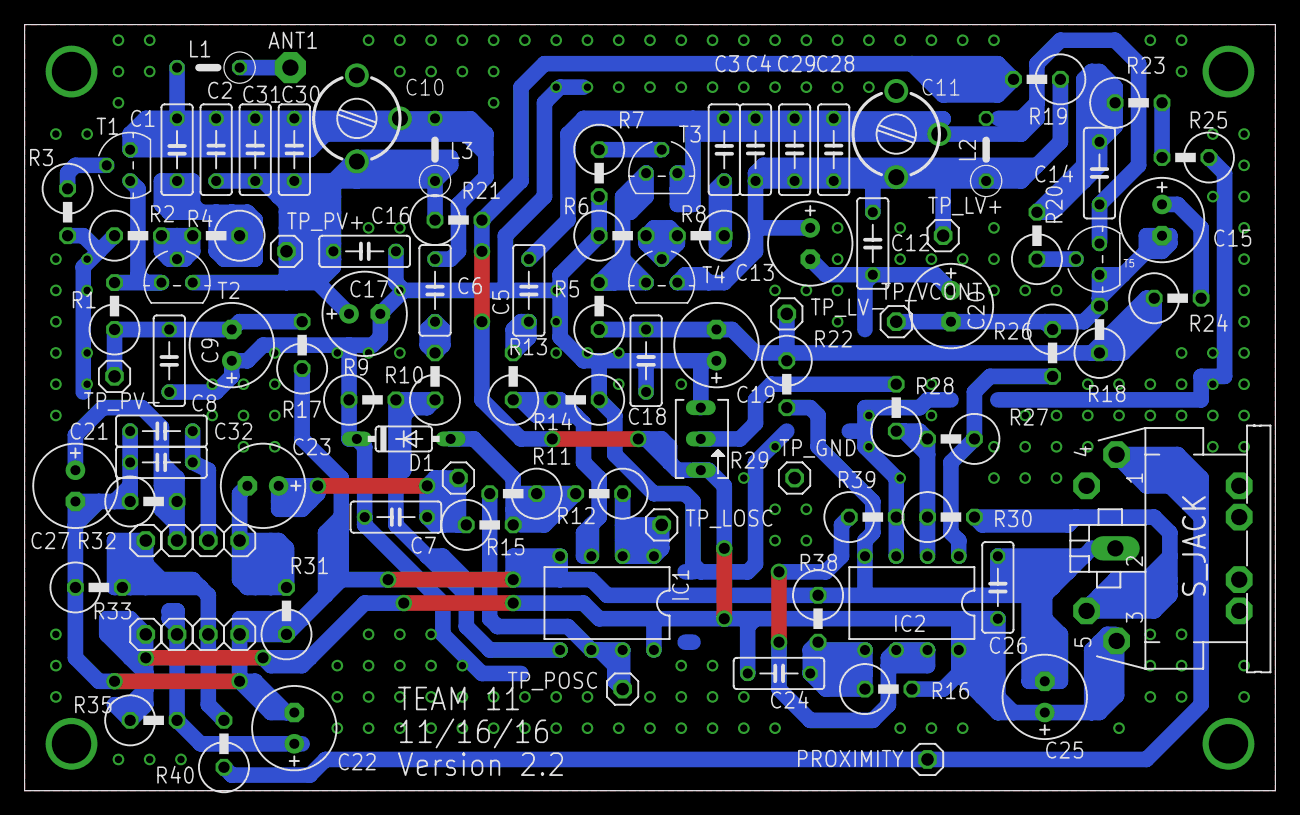
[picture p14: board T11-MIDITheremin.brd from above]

Board: 2 copper layers, 101.6 x 62.2 mm, 100 parts (0 on the bottom side), 42 nets.

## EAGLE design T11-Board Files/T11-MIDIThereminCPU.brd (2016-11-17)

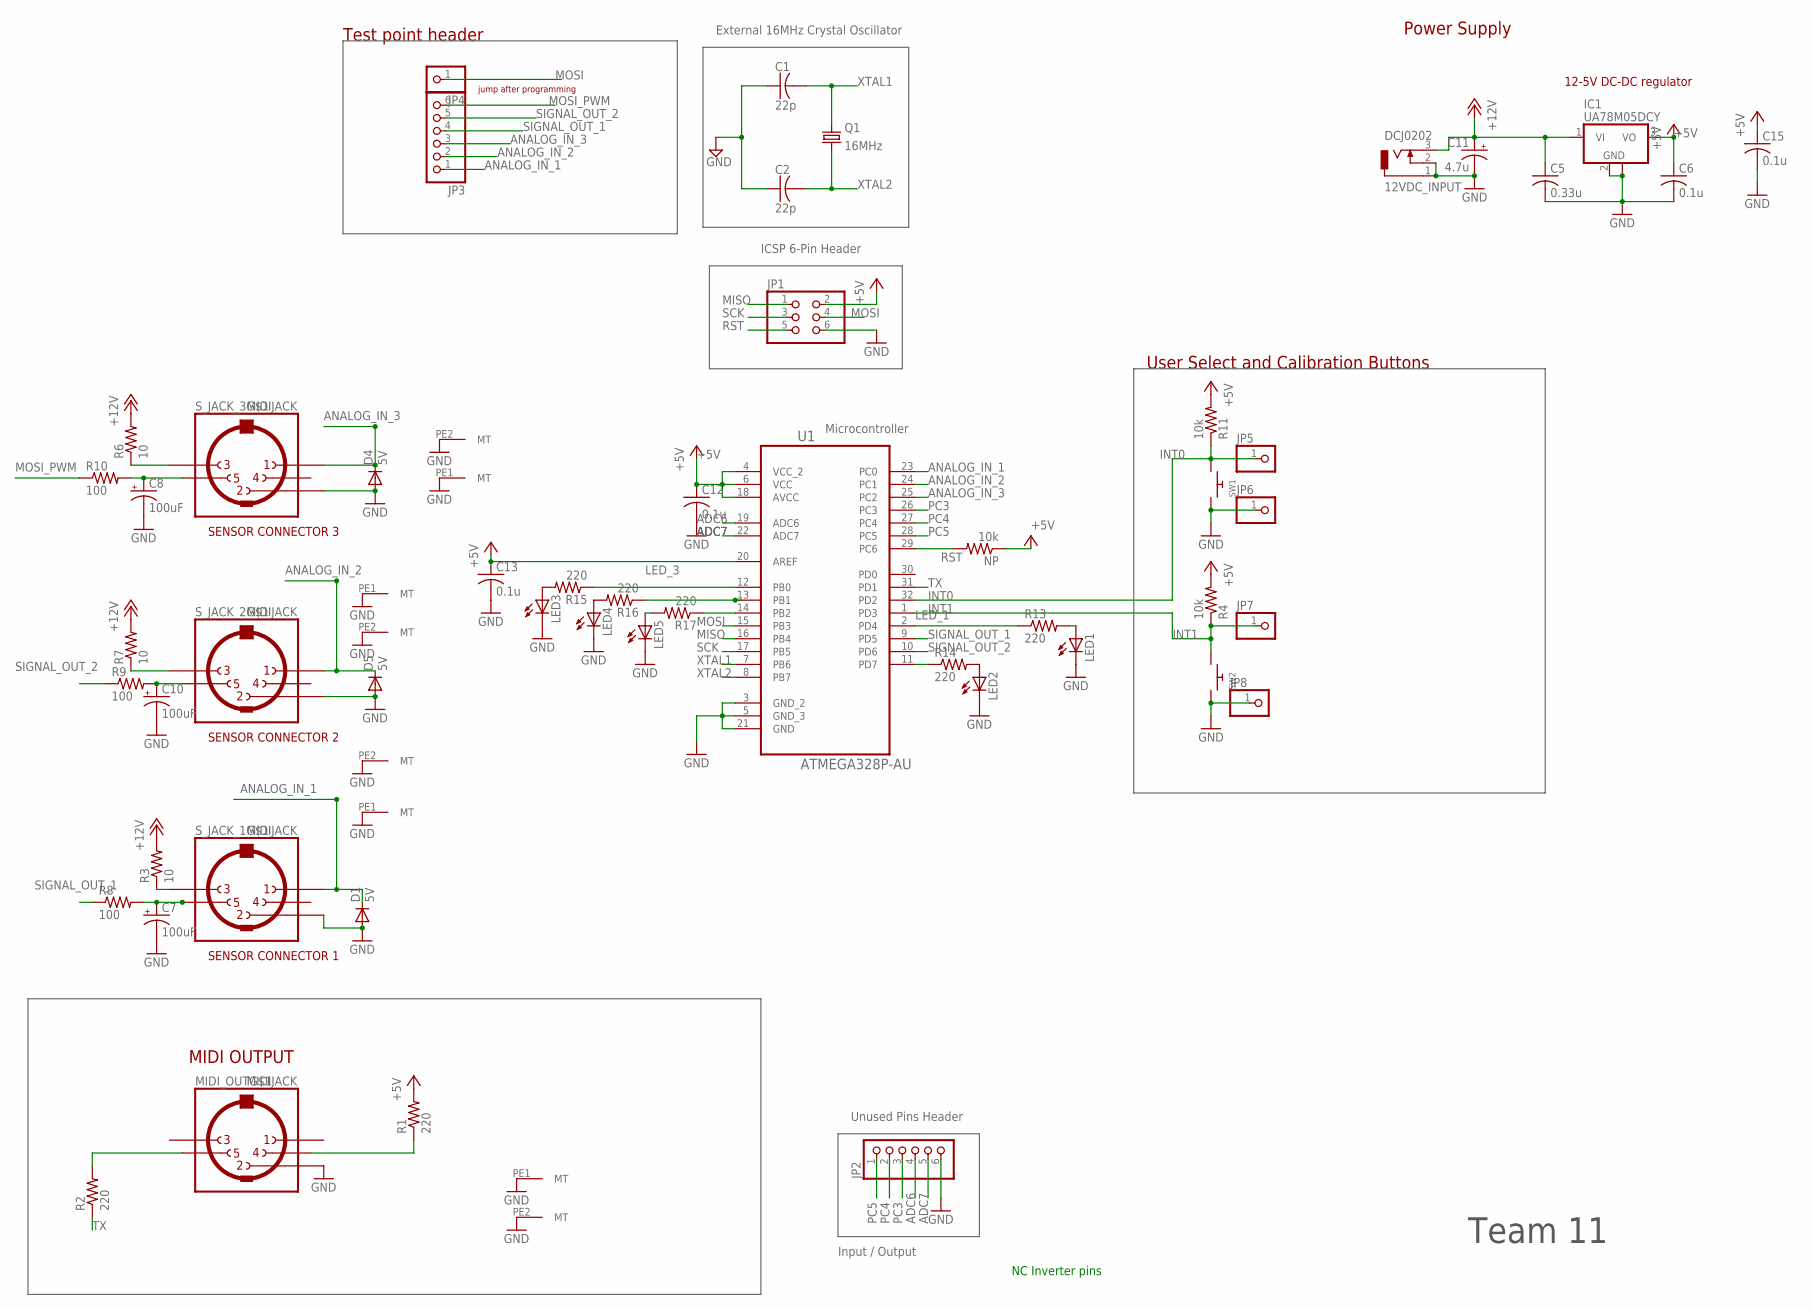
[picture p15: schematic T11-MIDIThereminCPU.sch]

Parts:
12VDC_INPUT: DCJ0202
C1, C2: 22p; C0805
C5: 0.33u; C0805
C6, C12, C13, C15: 0.1u; C0805
C7, C8, C10: 100uF; E3,5-8
C11: 4.7u; E3,5-8
D1, D4, D5: 5V; DO35-7
IC1: UA78M05DCY; SOT223
JP1: PINHD-2X3; 2X03
JP2, JP3: PINHD-1X6; 1X06
JP4, JP5, JP6, JP7, JP8: PINHD-1X1; 1X01
LED1, LED2, LED3, LED4, LED5: LED3MM
MIDI_OUT: MIDIJACK; CP-2350
NP: 10k; R0805
Q1: 16MHz; SM49
R1, R13, R14, R15, R16, R17: 220; R0805
R2: 220; M0805
R3, R7: 10; R0805
R4, R11: 10k; R0805
R6: 10; M0805
R8, R9: 100; R0805
R10: 100; M0805
SW1, SW2: SWITCH_PUSHBUTTONSOFTTOUCHSMD_SJ; PUSHBUTTON_SMD_SJ
S_JACK_1, S_JACK_2, S_JACK_3: MIDIJACK; CP-2350
U1: ATMEGA328P-AU; QFP80P900X900X120-32N

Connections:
+5V: C6.1, C12.1, C13.1, C15.1, IC1.3 (VO), JP1.2, NP.1, R1.2, R4.2, R11.2, U1.4 (VCC_2), U1.6 (VCC), U1.18 (AVCC), U1.20 (AREF)
+12V: 12VDC_INPUT.3, C5.1, C11.+, IC1.1 (VI), R3.2, R6.2, R7.2
ADC6: JP2.4, U1.19 (ADC6)
ADC7: JP2.5, U1.22 (ADC7)
ANALOG_IN_1: D1.C, JP3.1, S_JACK_1.1, U1.23 (PC0)
ANALOG_IN_2: D5.C, JP3.2, S_JACK_2.1, U1.24 (PC1)
ANALOG_IN_3: D4.C, JP3.3, S_JACK_3.1, U1.25 (PC2)
GND: 12VDC_INPUT.1, 12VDC_INPUT.2, C1.1, C2.1, C5.2, C6.2, C7.-, C8.-, C10.-, C11.-, C12.2, C13.2, C15.2, D1.A, D4.A, D5.A, IC1.2 (GND), IC1.4 (GND), JP1.6, JP2.6, JP6.1, JP8.1, LED1.K (C), LED2.K (C), LED3.K (C), LED4.K (C), LED5.K (C), MIDI_OUT.2, MIDI_OUT.PE1 (MT), MIDI_OUT.PE2 (MT), SW1.P$1, SW2.P$1, S_JACK_1.2, S_JACK_1.PE1 (MT), S_JACK_1.PE2 (MT), S_JACK_2.2, S_JACK_2.PE1 (MT), S_JACK_2.PE2 (MT), S_JACK_3.2, S_JACK_3.PE1 (MT), S_JACK_3.PE2 (MT), U1.3 (GND_2), U1.5 (GND_3), U1.21 (GND)
INT0: JP5.1, R11.1, SW1.P$2, U1.32 (PD2)
INT1: JP7.1, R4.1, SW2.P$2, U1.1 (PD3)
LED_1: R13.1, U1.2 (PD4)
LED_2: R14.1, U1.11 (PD7)
LED_3: R15.1, U1.12 (PB0)
LED_4: R16.1, U1.13 (PB1)
LED_5: R17.1, U1.14 (PB2)
MISO: JP1.1, U1.16 (PB4)
MOSI: JP1.4, JP4.1, U1.15 (PB3)
MOSI_PWM: JP3.6, R10.1
unnamed: MIDI_OUT.4, R1.1
unnamed: C8.+, R10.2, S_JACK_3.5
unnamed: LED1.A, R13.2
unnamed: R6.1, S_JACK_3.3
unnamed: LED2.A, R14.2
unnamed: C10.+, R9.2, S_JACK_2.5
unnamed: R3.1, S_JACK_1.3
unnamed: MIDI_OUT.5, R2.2
unnamed: LED3.A, R15.2
unnamed: LED4.A, R16.2
unnamed: LED5.A, R17.2
unnamed: R7.1, S_JACK_2.3
unnamed: C7.+, R8.2, S_JACK_1.5
PC3: JP2.3, U1.26 (PC3)
PC4: JP2.2, U1.27 (PC4)
PC5: JP2.1, U1.28 (PC5)
RST: JP1.5, NP.2, U1.29 (PC6)
SCK: JP1.3, U1.17 (PB5)
SIGNAL_OUT_1: JP3.4, R8.1, U1.9 (PD5)
SIGNAL_OUT_2: JP3.5, R9.1, U1.10 (PD6)
TX: R2.1, U1.31 (PD1)
XTAL1: C1.2, Q1.2, U1.7 (PB6)
XTAL2: C2.2, Q1.1, U1.8 (PB7)

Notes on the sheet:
External 16MHz Crystal Oscillator
ICSP 6-Pin Header
Power Supply
SENSOR CONNECTOR 1
MIDI OUTPUT
Input / Output
User Select and Calibration Buttons
Unused Pins Header
Test point header
Team 11
12-5V DC-DC regulator
Microcontroller
NC Inverter pins
SENSOR CONNECTOR 2
SENSOR CONNECTOR 3
jump after programming

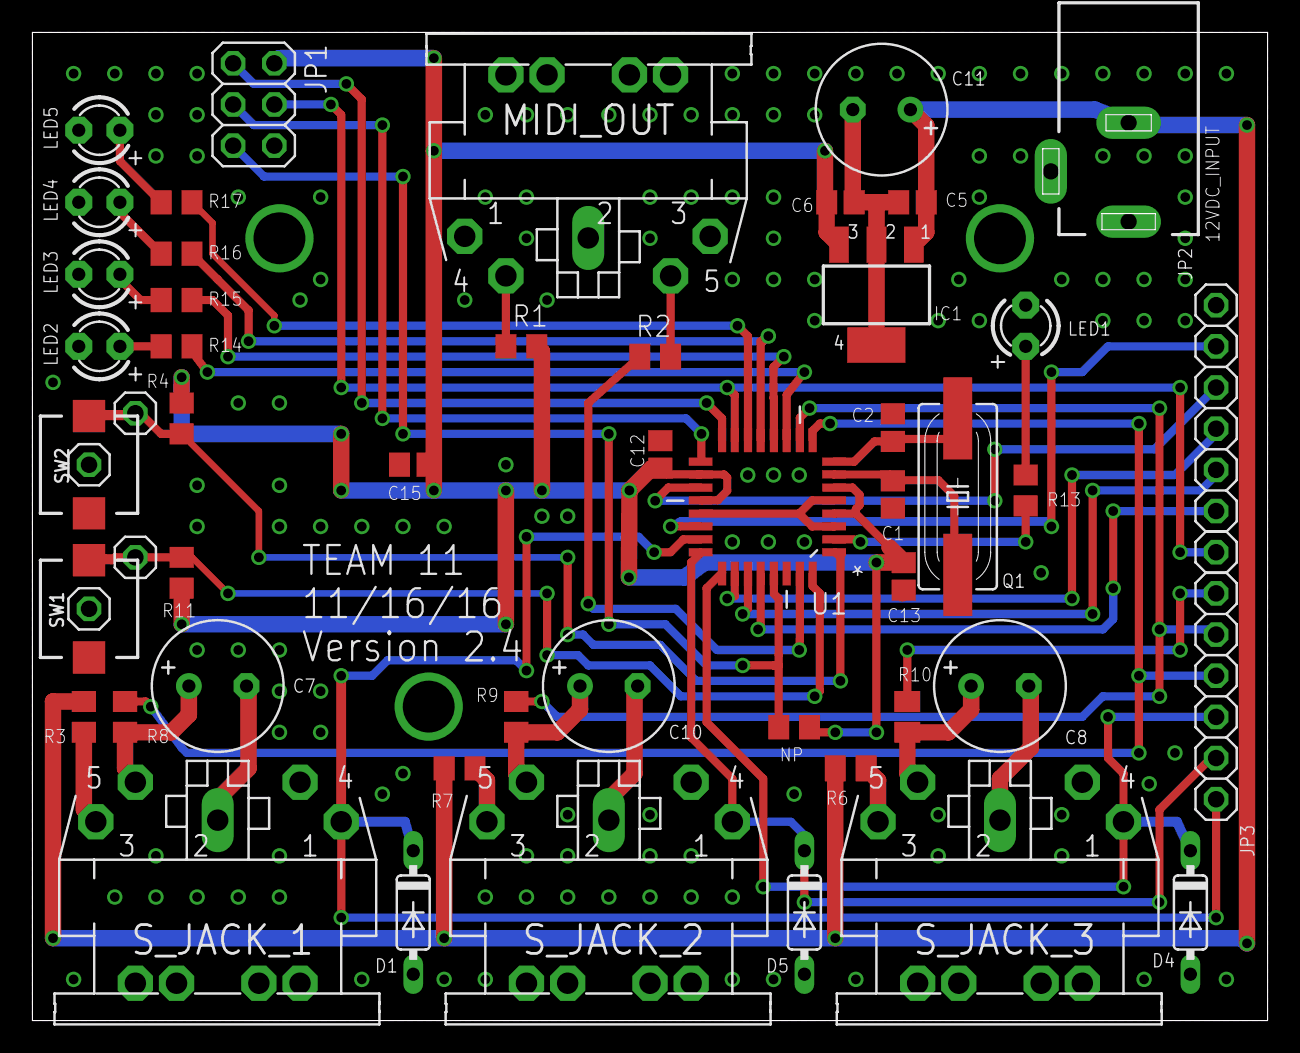
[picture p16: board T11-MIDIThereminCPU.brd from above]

Board: 2 copper layers, 76.2 x 61.0 mm, 53 parts (0 on the bottom side), 41 nets.

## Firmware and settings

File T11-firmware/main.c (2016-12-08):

#define F_CPU 16000000UL 
#define BAUD 31250
#define MYUBRR F_CPU/16/BAUD-1


/* Comment out the "#define DEBUG 1" line to turn off debugging output
!!!!!-WARNING-!!!!! Turn OFF debugging (comment out line) before enabling 
MIDI, since MIDI needs to use the USART at a different BAUD rate. */
//#define DEBUG 1

#include "main.h"
#include <avr/io.h> 
#include <util/delay.h>
#include <stdint.h>
#include "pwm.h"
#include "usart.h"
#include "analog.h"
#include "led.h"
#include "buttons.h" 
#include "calibration.h"
#include "mode1.h"

void main( void )
{
	/*
	Initialization Stuff should go here. 
	This can include initial calibration
	*/
	InitializePorts();
	
	// InitialPWMValue and other global variables found in main.h
	// Enables PWM Sensors, and sets the initial value. 	
	InitializeSensors(InitialPWMValue); 

	// If DEBUG is NOT defined, then allow MIDI
	#ifndef DEBUG
		MIDI_Init();
	#endif

	/* 
	If DEBUG is defined, enable UART for sending data over TX port
	*/
	#ifdef DEBUG
		// Initialize serial port for sending debug data
		USART_Init(25); // BAUD rate 38400
		USART_TransmitString("DEBUG is enabled.", 17); 
	#endif

	/*
	This is the main polling loop. With the exception of function calls, 
	the microcontroller should stay here while powered, and after the 
	initialization. 
	*/
	
	while(1)
	{
		#ifdef DEBUG
			USART_Transmit(PWMValue1); 
		#endif
		HandleButtonOnePress();
		HandleButtonTwoPress(); 

		switch(CurrentMode)
		{
			case IDLE: 
				//Do Nothing
				break;
			case MODE_1:
				curMidi = updatePitchChangeMode(1, ADC_THRESHOLD, 2, lowMidi, curMidi);
				break;
			case MODE_2: 
				// Do MODE2 stuff
				break;
			case MODE_3: 
				// Do MODE3 stuff
				break;
			case CALIBRATION:
				PWMValue1 = AutoCalibrate_1(CALIBRATION_START_VOLTAGE, ADC_THRESHOLD);
				PWMValue2 = AutoCalibrate_2(CALIBRATION_START_VOLTAGE, ADC_THRESHOLD);
				PWMValue3 = AutoCalibrate_3(CALIBRATION_START_VOLTAGE, ADC_THRESHOLD);
				CurrentMode = IDLE;
				break; 
		}

	}
}




void InitializePorts(void){
	#ifdef DEBUG
		USART_TransmitString("Ports are being initialized.", 28); 
	#endif

	// Initialize PinD2 as input
	DDRD &= ~(1<<DDD2);
	// Initialize PinD3 as input
	DDRD &= ~(1<<DDD3);

	// Set PD4 port as output. Initialize as off.
	DDRD |= (1 << DDD4);
	PORTD &= ~(1<<DDD4);
	// Set PD7 port as output. Initialize as off.
	DDRD |= (1 << DDD7);
	PORTD &= ~(1<<DDD7);
	// Set PB0 port as output. Initialize as off.
	DDRB |= (1 << DDB0);
	PORTB &= ~(1<<DDB0);
	// Set PB1 port as output. Initialize as off.
	DDRB |= (1 << DDB1);
	PORTB &= ~(1<<DDB1);
	// Set PB2 port as output. Initialize as off.
	DDRB |= (1 << DDB2);
	PORTB &= ~(1<<DDB2);

}




void InitializeBuffer(int* ADC_Buffer1){
	#ifdef DEBUG
		USART_TransmitString("The buffer is being initialized.", 32); 
	#endif

	// Initalize all values of ADC_Buffer1 to 0
	unsigned int i = 0;
	for (i=0; i<=(numSam - 1); i++){
    	ADC_Buffer1[i] = 0;
	}
}




void InitializeSensors(unsigned char Voltage){
	#ifdef DEBUG
		USART_TransmitString("Autocalibration.", 16); 
	#endif

	// Perform initialization
	PWM_On_PD5(Voltage); //Sensor 1
	PWM_On_PD6(Voltage); //Sensor 2
	PWM_On_PB3(Voltage); //Sensor 3

}








// Function to buffer and average the analog_read values
int Average_PC0(int* ADC_Buffer1){

	unsigned char i = 0;
	int ADC_Total = 0;
	int val = AnalogRead_PC0();

	// Shifts all data in the array one space left
	for (i=0; i<(numSam - 1); i++){
    	ADC_Buffer1[i] = ADC_Buffer1[i+1] ;
	}
	// Fills in the last space in the buffer with the new analog_read value
	ADC_Buffer1[numSam - 1] = val;

	// Averages the numbers in the buffer
	for (i=0; i<=(numSam - 1); i++){
    	ADC_Total += ADC_Buffer1[i];
	}
	ADC_Total = ADC_Total/numSam;

	return ADC_Total;
}

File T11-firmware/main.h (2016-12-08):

#define LINEFEED 10
#define CARRIAGERETURN 13

#define DelayOn 50
#define DelayOff 100
#define CALIBRATION_START_VOLTAGE 51
#define ADC_THRESHOLD 20 // 20 has been used multiple times and confirmed working
#define numSam 8         // number of samples for averaging buffer

/* These are sensor values */
#define f0 50
#define f1 60
#define f2 70
#define f3 80
#define f4 96
#define f5 128
#define f6 256
#define f7 384
#define m0 512
#define m1 640
#define c0 768
#define c1 896
#define c2 960

// Global variables
#define InitialPWMValue 127
unsigned char PWMValue1 = InitialPWMValue; 
unsigned char OldPWMValue1 = InitialPWMValue; 
unsigned char PWMValue2 = InitialPWMValue; 
unsigned char OldPWMValue2 = InitialPWMValue; 
unsigned char PWMValue3 = InitialPWMValue; 
unsigned char OldPWMValue3 = InitialPWMValue; 

//Mode stuff
#define IDLE 0
#define MODE_1 1
#define MODE_2 2
#define MODE_3 3
#define CALIBRATION 4
unsigned char CurrentMode = IDLE;

//MIDI Stuff
#define NoteON 0x90
#define NoteOFF 0x80
unsigned char lowMidi = 36; 
unsigned char curMidi = 36; 

//Averaging Stuff
unsigned char AverageCount = 0; 
unsigned char AverageTotal = 16; 
unsigned int AverageArray[16]; 
 
// Functions
void InitializePorts(void);
void InitializeBuffer(int* ADC_Buffer1);
void InitializeSensors(unsigned char Voltage);
int IsButtonOnePressed(void);
int IsButtonTwoPressed(void);
void BlinkLED_PD4(unsigned char NumOfBlinks);
void BlinkLED_PD7(unsigned char NumOfBlinks);
void BlinkLED_PB0(unsigned char NumOfBlinks);
void BlinkLED_PB1(unsigned char NumOfBlinks);
void BlinkLED_PB2(unsigned char NumOfBlinks);
int AnalogRead_PC0(void);
int AnalogRead_PC1(void);
int AnalogRead_PC2(void);
int Average_PC0(int* ADC_Buffer1);

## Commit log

2016-10-25 Add files via upload
    Updated schematic to include frequency to voltage circuit
    [MIDITheremin10-24.sch]
2016-10-28 Add files via upload
    Started a parts list
    [Parts List.ods]
2016-10-28 These are updated Schematics
    updated schematic and PCB
    [MIDITheremin10-24.brd, MIDITheremin10-24.sch]
2016-10-30 Added power input
    Added DC barrel jack and 5v and 3.3v regulated sources
    [MIDIThereminCPU.sch]
2016-11-01 Labeled power section and added MIDI I/O
    [MIDIThereminCPU.sch]
2016-11-01 Removed 3.3V, connected MIDI
    [MIDIThereminCPU.sch]
2016-11-02 Added LED and push button, MIDI hookup refinement.
    Added a 7-seg LED display and debounced push button. Grounded MIDI shields and added optional ferrite beads to MIDI out as per MIDI 2014 specifications.
    [MIDIThereminCPU.sch]
2016-11-02 Fixed some part connections
    Changed midi output signals from pins 1 and 3 to 4 and 5. Reversed orientation of zener diode on MIDI in.
    [MIDIThereminCPU.sch]
2016-11-03 Added LEDs, button 2, midi jacks
    Removed the 7-segement LED and replaced it with 5 LEDs, added a second debounced button, added 2 more midi jacks to sensor board connections.
    [MIDIThereminCPU.sch]
2016-11-03 Changes per discussion
    [MIDIThereminCPU.sch]
2016-11-03 changes per discussion
    added test points and unused pin headers. pull up resistor on reset. are +5V. barrel jack wired correctly.
    [MIDIThereminCPU.sch]
2016-11-03 renamed theremin boards
    [MIDITheremin.brd, MIDITheremin.sch, MIDITheremin10-24.sch]
2016-11-03 Drew connections
    Drew in the connections. These look horrible and only connect to labeled points on the arduino, so I don't see the point but oh well.
    [MIDIThereminCPU.sch]
2016-11-04 Added PWM support for PD5 and PD6.
2016-11-04 Appended T11- to files.
    [T11-MIDITheremin.brd, T11-MIDITheremin.sch, T11-MIDIThereminCPU.sch]
2016-11-05 Added amplifiers
    Added adjustable amplification onto the return signal from sensor
    board. Named ICs. Some rearrangement.
    [T11-MIDIThereminCPU.sch]
2016-11-08 Added ferrite bead values
    [T11-MIDIThereminCPU.sch]
2016-11-09 Changed filter values
    [T11-MIDIThereminCPU.sch]
2016-11-10 Some Package Changes
    [T11-MIDIThereminCPU.brd]
2016-11-10 Board creation
    [T11-MIDIThereminCPU.brd, T11-MIDIThereminCPU.sch]
2016-11-10 Changed resistors and caps to smd
    [T11-MIDIThereminCPU.brd, T11-MIDIThereminCPU.sch]
2016-11-10 Improved routing, coupling caps added
    [T11-MIDIThereminCPU.brd, T11-MIDIThereminCPU.sch]
2016-11-10 Improved routing, added coupling caps
    [T11-MIDIThereminCPU.brd]
2016-11-10 Fixed DRC errors
    [T11-MIDIThereminCPU.brd]
2016-11-10 Updated CPU board progress
2016-11-11 Added PWM support for PB3. Wrote functions to allow change of PWM Duty Cycle, to avoid redundant initialization of the ports.
    [main.c, pwm.c]
2016-11-11 Add files via upload
    still needs a board name
    [T11-MIDIThereminCPU.brd]
2016-11-14 Created BOM, updated parts
    [T11-MIDIThereminCPU.brd, T11-MIDIThereminCPU.sch]
2016-11-14 Removed option to change frequency due to issues. Will re-implement if it becomes necessary. Currently, PWM is set to around 8 kHz.
    [main.c, pwm.c]
2016-11-15 Changed PWM frequency back.
2016-11-16 Fixed ERC errors. Added revision and date to CPU schematic.
2016-11-16 Fixed Unrouted wires. Added Team Number and Revision.
2016-11-16 Added date to CPU Board. Removed b#x and s#x files.
    [T11-MIDIThereminCPU.brd]
2016-11-16 added a jumper to the MOSI line for programming
    [T11-MIDIThereminCPU.brd, T11-MIDIThereminCPU.sch]
2016-11-17 removed debounce circuit. added vias
    [T11-MIDIThereminCPU.brd, T11-MIDIThereminCPU.sch]
2016-11-17 added optional panel mount buttons
    [T11-MIDIThereminCPU.brd, T11-MIDIThereminCPU.sch]
2016-11-17 fixed some of the silkscreen layer
    [T11-MIDITheremin.brd, T11-MIDITheremin.sch]
2016-11-22 Added code for button presses, and for one of the LEDs.
2016-12-07 organizational changes
    [T11-MIDITheremin.brd, T11-MIDITheremin.sch, T11-MIDIThereminCPU.brd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]
2016-12-07 Buttons to allow manual calibration
2016-12-07 Sensor 1 Calibration working
2016-12-07 Sensor 2 working
2016-12-07 Sensor 3 Calibration working
2016-12-07 All 3 calibration sequences confirmed working successively.
2016-12-07 Sensor1 Calibration with LED indicator working.
2016-12-07 Sensor 2 Calibration with LED indicator working.
2016-12-07 Sensor 3 Calibration with LED indicators working.
2016-12-07 All 3 sensor calibrations with LED indicators working, with MIDI Initialized.
2016-12-07 Moved global variables to main.h. Created defines for passed values to calibration function.
2016-12-07 Mode switching capability added. Confirmed ability to switch between modes, including calibration, which still works properly.
2016-12-07 Moved button press code to buttons.c. Tested button press code, mode switching, LED indicators and Calibration. All working.
2016-12-08 Working, no MEAN, no velocity logarithm
2016-12-08 Mean for pitch working
